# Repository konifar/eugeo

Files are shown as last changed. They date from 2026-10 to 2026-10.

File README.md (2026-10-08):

# eugeo

6 キー × 4 行 × 2 ブロック（48 キー）のスルーホール・オーソリニア 40% キーボード PCB です。
[Lumberjack](https://github.com/peej/lumberjack-keyboard)（Paul James 作、MIT License）をベースに、行を 1 段減らし、Kailh の MX 用ホットスワップソケットに対応させました。

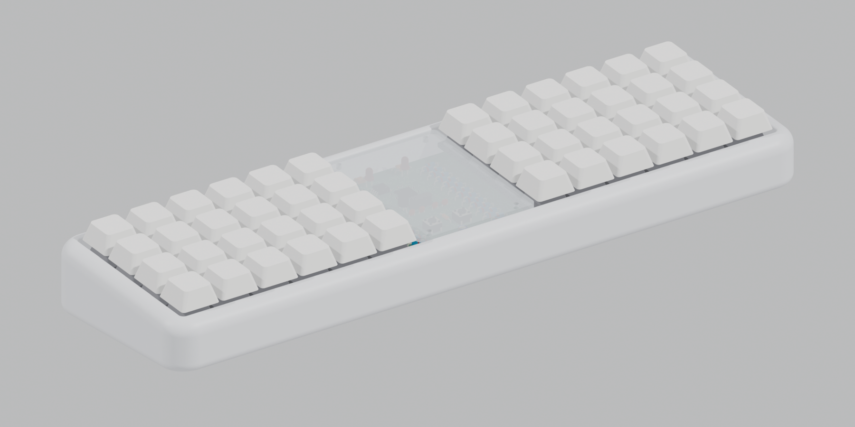
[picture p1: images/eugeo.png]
eugeo


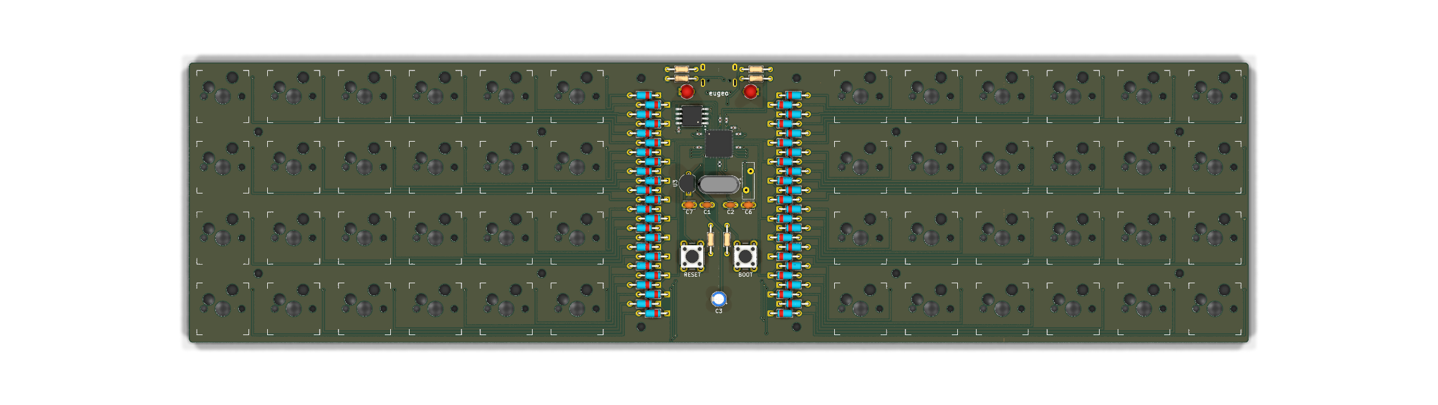
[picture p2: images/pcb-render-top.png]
PCB render


| 真上 | 背面 | 側面（6°） |
|---|---|---|
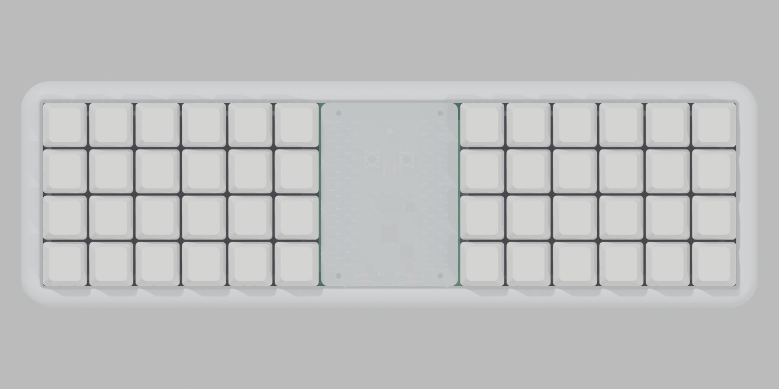
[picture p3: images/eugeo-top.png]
top
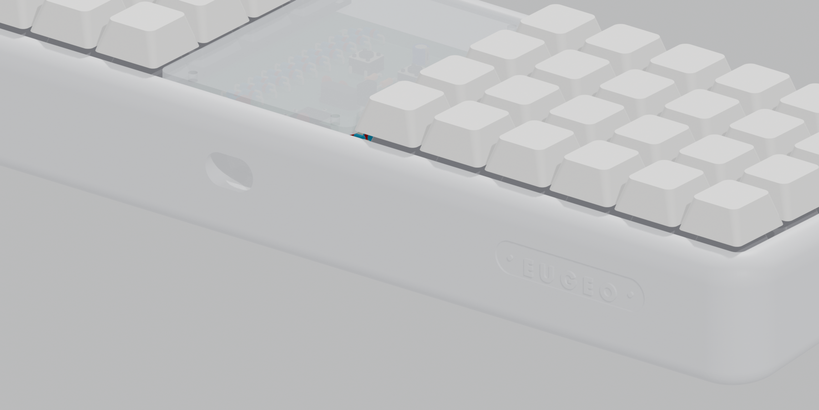
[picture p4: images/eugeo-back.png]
back
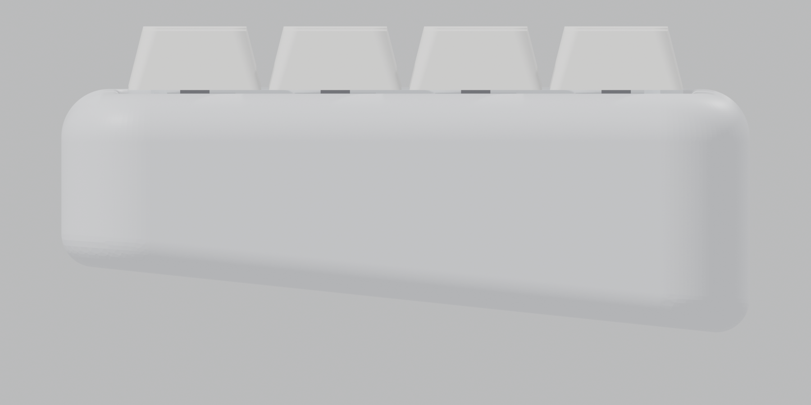
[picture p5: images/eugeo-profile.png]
profile
|  |  |  |

組み上がりの画像のスイッチとキーキャップは、大きさと位置の目安として置いた簡易形状です（`scripts/preview_models.py`）。

## Lumberjack からの変更点

| | Lumberjack Rev 1.8 | eugeo Rev 1.0 |
|---|---|---|
| 配列 | 5 × 12（60 キー） | 4 × 12（6 × 4 × 2、48 キー） |
| スイッチ | はんだ付け | Kailh MX ホットスワップソケット（裏面） |
| マトリクス | 6 行 × 10 列 | 8 行 × 6 列（後述） |
| USB-C | 左上・裏面 | 中央上・裏面（ソケットとの干渉回避） |
| 外形 | 60% トレイマウントケース互換 | 284.9 × 75.35 mm、M2 穴 8 箇所でサンドイッチ |
| ドーターボード用コネクタ (J3-J5) | あり | 削除 |
| 中央カバー | 2 mm アクリル、M2 10 mm スペーサー 4 本 | 同じ構成（ネジはカバーの四隅） |
| マイコン | ATmega328P-PU（DIP）+ V-USB（USB 1.1 Low Speed） | RP2040 + 2 MB QSPI フラッシュ（USB Full Speed、UF2 書き込み） |
| 電源 | USB 5 V 直結 | MCP1700 で 3.3 V（TO-92） |
| 書き込み | ISP ヘッダ（2x3） | BOOT ボタン + USB（UF2）。ISP ヘッダは不要になったので削除 |

マイコンまわりの表面実装部品（RP2040、フラッシュ、0402 のコンデンサなど）は JLCPCB に実装してもらい、それ以外はスルーホール部品のまま残しています。
上部の左右に 1 個ずつの LED、水晶（HC49）、セラミック・電解コンデンサ、LDO（TO-92）、アキシャル抵抗、タクトスイッチ、ダイオード列が中央に並ぶ、Lumberjack の「部品を見せる」見た目を踏襲しています。

## マトリクス

左右のブロックで行を分け、列を共有させた 8 行 × 6 列です。
左右の対称位置の列（左 C0 と右 C11 など）を基板下端の 1 本の配線で共有するので、ROW の配線が MCU をまたがずに済みます。
RP2040 の左辺のピンから左ブロックの行・列 3 本・LED1、右辺のピンから右ブロックの行・列 3 本・LED2 を出し、下辺は水晶と RUN、上辺は QSPI フラッシュと USB に使っています。

| 物理位置 | マトリクス |
|---|---|
| 左ブロック (row r, col c) | ROW r, COL c |
| 右ブロック (row r, col 6+j) | ROW r+4, COL 5-j |

| 設定 | 値 |
|---|---|
| MATRIX_ROW_PINS | GP3, GP4, GP5, GP6, GP26, GP25, GP24, GP23 |
| MATRIX_COL_PINS | GP9, GP10, GP11, GP20, GP19, GP18 |
| DIODE_DIRECTION | COL2ROW |
| LED1 (赤) / LED2 (緑) | GP1 / GP28（上部の左右） |
| BOOT ボタン | QSPI_SS（RP2040 標準の BOOTSEL。1k 経由で GND に落とす） |

## ファイル構成

| パス | 内容 |
|---|---|
| `eugeo.kicad_pro` / `.kicad_sch` / `.kicad_pcb` | KiCad 9 プロジェクト |
| `symbols/`, `footprints/eugeo.pretty/` | プロジェクト専用シンボル・フットプリント（ホットスワップソケット、USB-C、M2 穴） |
| `plates/` | スイッチプレート（左右共通、2 枚注文）、中央カバー、ボトムプレートの KiCad データと DXF |
| `case/` | Mojo60 風の丸いトレイケースと中央カバーの STEP / STL |
| `foam/` | プレートフォームとケースフォームの DXF と原寸 PDF |
| `lasercut/yushakobo/` | 遊舎工房レーザー加工サービス用の SVG（中央カバー / スイッチプレート / フォーム） |
| `jlcpcb/` | JLCPCB 実装用 BOM / CPL（表面実装部品とホットスワップソケット） |
| `jlcpcb/full/` | USB-C とスルーホール部品まで JLCPCB に実装してもらう場合の BOM / CPL |
| `gerbers/*.zip` | 製造用ガーバー（PCB、プレート、ボトム） |
| `firmware/qmk/keyboards/eugeo/` | QMK 用キーボード定義とキーマップ（default / via） |
| `firmware/*.uf2` | ビルド済みファームウェア |
| `scripts/` | 回路図・基板・裏面アート（`stump_art.py`）を生成するスクリプト一式 |

## 生成手順

回路図と基板は `scripts/design.py` を唯一の定義として生成しています。
部品配置やネットを変えるときは `design.py` を編集して再生成してください。

```bash
FREEROUTING_JAR=/path/to/freerouting-2.1.0.jar scripts/build_all.sh
```

1. `gen_schematic.py` で回路図を生成し、`check_netlist.py` で `design.py` とネットを照合
2. `build_pcb.py` で部品配置と、キー部分・ダイオード列・USB 端子・RP2040 まわりの配線を引く。RP2040 は電源ピンをパッドの内側の +3V3 リングでまとめ、QSPI・水晶・パスコン・各ピンの引き出しまでを手配線している
3. `route.sh` で残り（引き出した先から各部品まで）を Freerouting 2.1.0 で自動配線
4. `cleanup_dangling.py` で余った配線を削除し、`fill_zones.py` で表裏の GND ベタを流し、`stump_art.py` で裏面のアートを描く
5. DRC（回路図との整合チェック込み）

Freerouting の結果は実行ごとに変わり、まれに未配線が残ります。その場合は `build_all.sh` を再実行してください。
Freerouting 2.1.0 は Java 21 で動きます（2.2 以降は Java 25 が必要）。
初回起動時にできる設定ファイル（macOS では `$TMPDIR/freerouting/freerouting.json`）はテレメトリが有効なので、`allow_telemetry` を `false` にしておくことを勧めます。

製造データは次のコマンドで出力します。

```bash
scripts/export_fab.sh
```

## 製造（JLCPCB）

2026-10-06 に JLCPCB / JLC3DP の見積もりページへアップロードし、次のとおり受け付けられることを確認しました（カート投入・注文はしていません）。

| 部品 | ファイル | JLCPCB の認識 | 見積もり（参考） |
|---|---|---|---|
| PCB | `gerbers/eugeo.zip` | 2 層、284.9 × 75.35 mm | 5 枚 ¥2,269 + 送料 ¥1,536 |
| スイッチプレート | `gerbers/eugeo-plate.zip` | 2 層、113.45 × 75.35 mm。外形レイヤーにスイッチ穴 24 個と M2 穴 4 個 | 5 枚 ¥630 |
| ケース | `case/eugeo-case.step` | 302.9 × 93.4 × 29.9 mm、198.09 cm³（ふちを上げる前の版） | 9600 Resin 白 1 個 ¥2,978 + 送料 ¥1,139 |

PCB の注文設定は既定値（FR-4、1.6 mm、HASL）のままで問題ありません。色は好みで変えてください。
スイッチプレートは銅箔のない基板として注文します。JLCPCB の 2D プレビューでは穴が描かれませんが、Gerber Viewer の Layers 表示で外形に穴が入っていることを確認できます。左右共通なので 2 枚以上あれば足ります。
ボトムプレート（`gerbers/eugeo-bottom.zip`）はケースを使わない場合だけ必要です。

ケースは JLC3DP の 3D Printing で `case/eugeo-case.step`（または `.stl`）をアップロードし、素材に SLA レジン（9600 Resin など）を選びます。
最大造形サイズ（9600 Resin は 780 × 780 × 530 mm）には十分収まります。

### 表面実装部品とソケットの実装を JLCPCB に頼む

RP2040 まわりの表面実装部品（表面）とホットスワップソケット 48 個（裏面）を JLCPCB の PCBA で実装し、残りのスルーホール部品は自分ではんだ付けする想定です。
表裏両面の実装になるので Standard PCBA を選び、Assembly Side は **Both Sides** にして次のファイルをアップロードします。

| ファイル | 内容 |
|---|---|
| `jlcpcb/eugeo-bom.csv` | ソケット（LCSC C41430893）と表面実装部品（RP2040 C2040、W25Q16JVSSIQ C131025、USBLC6-2SC6 C7519、0402 のコンデンサ・抵抗。R7 / R8 / C12 / C13 / U4 は裏面） |
| `jlcpcb/eugeo-cpl.csv` | 実装座標（ガーバーと同じ原点）。ソケットは本体中心・裏面・回転 0、表面実装部品は KiCad の部品位置 |

2026-10-08 に実際にアップロードして確認した結果です（カート投入・注文はしていません）。

- ガーバー: 2 層、284.9 × 75.35 mm として受け付け。Standard PCBA では JLCPCB が上下に 5 mm の捨て基板（エッジレール）を付けるので、届いた基板はレールを折って外す（有料の Depanel オプションで外してもらうこともできる）
- BOM: 7 品目すべてが LCSC 部品に一致（RP2040 C2040、W25Q16JVSSIQ C131025、USBLC6-2SC6 C7519、0402 のコンデンサ・抵抗、ソケット C41430893）
- 部品配置プレビューで、RP2040・フラッシュ・USBLC6 の 1 番ピンとリードがフットプリントに合うことを確認。KiCad の角度のままではフラッシュ（SOIC-8、表）と USBLC6（SOT-23-6、裏）が 90° ずれていたので、`scripts/export_jlc_pcba.py` の `ROT_OFFSET` で補正済み。USBLC6 は 180° 間違えると GND と VBUS が入れ替わるので、部品を変えたときは必ずプレビューで確かめる
- ソケットの回転は 2026-10-06 に確認済み（突起が φ3.05 穴に、端子がパッドに重なる）
- 見積もり: 5 枚で ¥18,706（PCB ¥2,490、PCBA ¥16,215。うち初期費用 ¥8,117、ステンシル ¥2,607、部品 ¥3,406）、送料別

Kailh 純正ソケット（C5184526）にしたい場合は `scripts/export_jlc_pcba.py` の `LCSC` を書き換えてください。

### すべての部品の実装を JLCPCB に頼む

USB-C とスルーホール部品（ダイオード 48 本、抵抗、コンデンサ、水晶、レギュレータ、ヒューズ、タクトスイッチ、LED）まで JLCPCB に付けてもらう場合は、`jlcpcb/` の代わりに `jlcpcb/full/` をアップロードします（`python3 scripts/export_jlc_pcba.py --full` で生成）。はんだ付けは不要になり、届いたらスイッチを挿すだけです。

2026-10-08 にアップロードして確認した結果です（カート投入・注文はしていません）。

- BOM: 22 品目すべてが LCSC 部品に一致し、在庫あり
- スルーホール部品の座標は KiCad の原点（1 番ピン）ではなくパッドの中心にしている。USB-C は SMD なので部品位置のまま
- 部品配置プレビューで向きを確認。JLCPCB のモデルでは 3 mm LED のカソードと USB-C の差し込み口が逆向きだったので、`ROT_OFFSET` で 180° 補正済み
- 見積もり: 5 枚で ¥27,679（PCB ¥2,490、PCBA ¥25,188。うち初期費用 ¥8,117、ステンシル ¥2,607、部品 ¥6,949、フィーダー ¥1,954、手はんだ ¥569、手作業実装 ¥1,989、治具 ¥2,607）、送料別。表面実装部品とソケットだけの場合より ¥8,973 高い
- コンデンサ C6 / C7（C1620326）は単価が高く在庫も少なめ（確認時 34 個）、レギュレータ U3（C511277）も在庫 349 個。注文時に在庫切れなら同等品に差し替える

## 裏面のデザイン

基板の裏面は「凍てついた切り株」がテーマです（`scripts/stump_art.py`、`build_all.sh` の中で自動生成）。

- 裏返して左側（表から見て右ブロックの 1 段目と 2 段目の間）に、ケース背面の刻印と同じ Futura の「EUGEO」ロゴを大きく入れている。文字の高さ 7.5 mm、両側に細い線と丸を添える。文字の輪郭は `scripts/logo_outline.py` で `scripts/logo_eugeo.json` に書き出したもの

- 中央に年輪・樹皮・干割れのある切り株をシルクで描き、左右の端に向かって霜の結晶（シダ状の霜）が伸びる
- キーの並ぶ部分にはシルクの雪の結晶を散らす
- 大きめの雪の結晶 7 個はソルダーレジストの開口で、GND ベタの銅がそのまま（HASL なら銀色に）見える。配線・ビア・穴のない GND ベタの上にだけ置く
- シルクはパッド・穴・既存の文字の周りで自動的に切り取り、DRC の警告が出ないようにしている

レジストの色は青（Blue）を勧めます。白いシルクと銀色の結晶が氷のように見えます。

## ケース

Mojo60 を意識した、角と上下のふちを大きく丸めた一体型のトレイケースです。

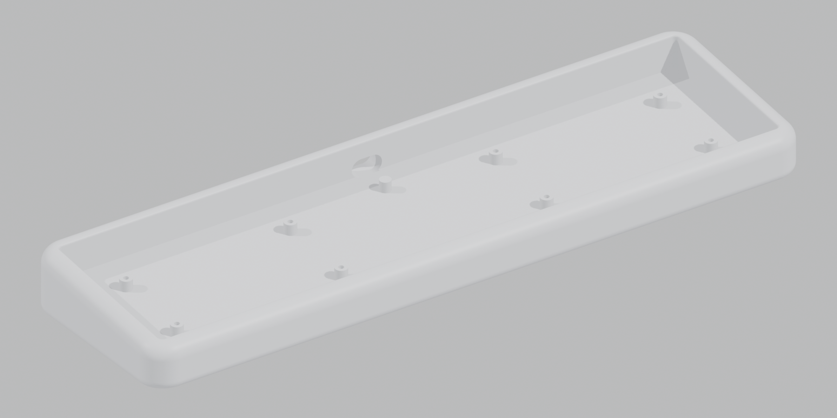
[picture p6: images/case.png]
Case


| 項目 | 値 |
|---|---|
| 外形 | 302.9 × 93.4 mm、高さ 手前 23.1 mm / 奥 32.9 mm |
| 傾斜 | 6° |
| 角の丸み | 平面 R12、上面のふち R6.5、底面のふち R4.5 |
| ふち | プレート上面から 6.5 mm 上（スイッチの上部が隠れ、キーキャップはその上に出る高さ） |
| 基板と壁のすき間 | 1.0 mm（キーキャップと壁の間は約 1.1 mm） |
| 底面 | 肉抜きして、幅 6 mm のふちで接地 |
| 刻印 | 奥の壁に「EUGEO」の銘板（後述） |

### 刻印

奥の壁の USB-C の横（背面から見て右）に、銘板風の刻印を入れています。
USB-C の切り欠きと同じ高さ 8.5 mm の長円を 0.6 mm 掘り下げ、Futura の「EUGEO」（文字高さ約 4.4 mm、字間広め）と両端の小さな鋲を元の壁面の高さで残しています。
USB-C の切り欠きと形・高さを揃えて、背面の 2 つの要素が並んで見えるようにしました。

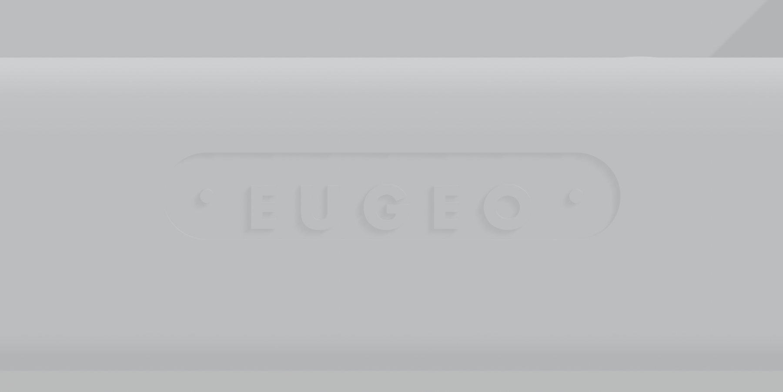
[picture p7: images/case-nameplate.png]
Nameplate


文字・フォント・位置・深さは `scripts/case.py` の `BADGE_*` 定数で変えられます。

寸法は `scripts/case.py` の先頭にある定数で変えられます。再生成の手順は次のとおりです。

```bash
uv venv --python 3.12 .venv && uv pip install --python .venv/bin/python build123d
.venv/bin/python scripts/case.py
kicad-cli pcb export step --subst-models -o /tmp/eugeo-pcb.step eugeo.kicad_pcb
.venv/bin/python scripts/check_case_fit.py /tmp/eugeo-pcb.step   # 基板・部品・プレートとの干渉チェック
```

### 組み立て

レジンには熱圧入インサートが使えないため、ネジはケースの底から通します。

1. 基板の上面から M2 3.5 mm のメス-メススペーサーを当て、ケースの底から M2×10 のなべネジで、ケースの支柱と基板を挟んで締める
2. スイッチをプレートにはめ、基板のソケットに差し込む
3. 必要ならプレートの上から M2×3 でスペーサーに留める（スイッチとソケットだけでも固定される）

奥の壁の USB-C 用の切り欠きは 14 × 8.5 mm です。プラグのモールド部分がこれより大きいケーブルは奥まで刺さりません。
底面のふちに小さいゴム足を貼ってください。

## 中央カバー

Lumberjack と同じく、中央の部品（ダイオード列・MCU・USB 周り）を透明な板で覆えます。

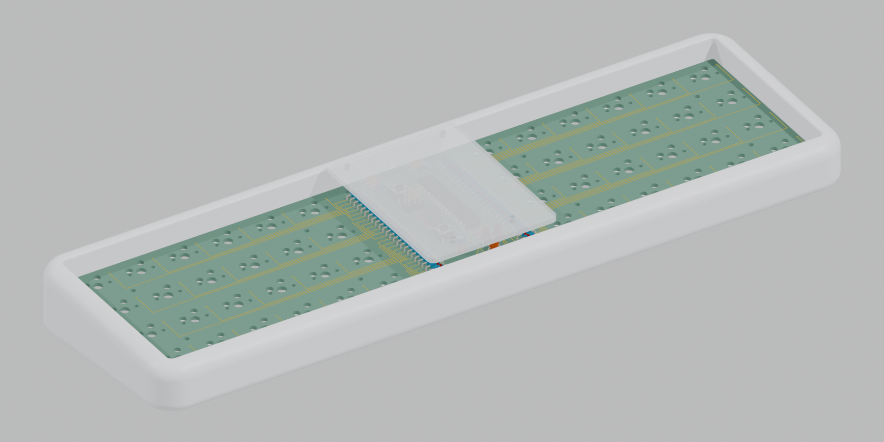
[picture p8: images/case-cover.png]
Centre cover


| 項目 | 値 |
|---|---|
| 大きさ | 56.2 × 75.35 mm、角 R3、厚さ 2 mm |
| 取り付け | カバーの四隅に合わせた基板の M2 穴 4 か所（H9〜H12）に M2 10 mm のメス-メススペーサーを立て、下から M2×4 で基板に、上から M2×4 でカバーを留める |
| 高さ | カバーの下面は基板上面から 10 mm。下でいちばん高い LED1（8.29 mm）との間に 1.71 mm のすき間 |
| ケースとの関係 | カバーの上面はケースのふちより約 0.5 mm 上。ケース・キーキャップとは重ならない |

| ファイル | 用途 |
|---|---|
| `plates/eugeo-cover.dxf` | アクリル板のレーザーカット用（推奨） |
| `case/eugeo-cover.step` / `.stl` | 3D プリントや CNC 用 |
| `gerbers/eugeo-cover.zip` | JLCPCB で FR4 板として作る場合（不透明になる） |

JLCPCB の基板サービスでは透明な板は作れないため、透明にしたい場合はアクリルのレーザーカットサービスに DXF を出してください。
JLC3DP の SLA で作る場合は、見積もり画面で透明系のレジンが選べるか確認してください。

## フォーム

打鍵音とたわみの調整用に、2 種類のフォームの型を用意しました。どちらも左右同じ形なので、1 つの型で 2 枚切り、片方は裏返して使います。

| ファイル | 位置 | 推奨素材 | 形 |
|---|---|---|---|
| `foam/eugeo-plate-foam` | プレートと PCB の間（3.5 mm） | 3 mm PORON | プレートと同じ外形、スイッチ下部を逃がす 14.5 mm 角穴、スペーサー用 φ4.4 穴 |
| `foam/eugeo-case-foam` | PCB とケース底の間（5 mm） | 3 mm PORON | キー部分のみ（中央の部品エリアは空ける）、ケースの支柱用 φ7 穴 |

`.dxf` はレーザーカット業者向け、`-1to1.pdf` は手で切るための原寸の型紙です。PDF は A4 横で、倍率 100% で印刷し、100 mm のスケールバーで寸法を確かめてから使ってください。
ケースフォームは 3 mm にすると、裏面のソケット（高さ約 1.85 mm）との間にほぼすき間がない厚さになります。
JLCPCB ではフォームのカットは扱っていないため、遊舎工房のレーザー加工（下記）に出すか手で切ってください。
スイッチプレート（`gerbers/eugeo-plate.zip`）は、ケースの内側に 1 mm のすき間で収まり、ケースのふちより 6.5 mm 低い位置に来ることを確認済みです。

## 遊舎工房のレーザー加工

[遊舎工房のレーザー加工サービス](https://yushakobo.jp/lasercut/)に、そのまま入稿できる SVG を `lasercut/yushakobo/` に用意しました。
遊舎工房配布の Inkscape テンプレートを土台にし、注文サイズの作業領域だけを残しています。

| ファイル | 注文するサービス / 素材 / 厚さ / サイズ | 中身 |
|---|---|---|
| `eugeo-cover_acrylic-clear-2mm_115x300.svg` | [レーザー加工サービス](https://shop.yushakobo.jp/products/lasercut)（アクリル）/ アクリル クリア / 2mm / 115x300 | 中央カバー 1 枚 |
| `eugeo-switch-plate_pom-1.5mm_245x245.svg` | [レーザー加工サービス（その2）](https://shop.yushakobo.jp/products/lasercut-2) / POM / 1.5mm / 245x245 | スイッチプレート 2 枚（左右共通） |
| `eugeo-foam_poron-3mm_500x100.svg` | レーザー加工サービス（その2）/ PORON / 3mm / 500x100 | プレートフォーム 2 枚 + ケースフォーム 2 枚 |

- 穴などの内側はカット①（赤）、外形はカット②（青）です。内側を先に切ってから部品を切り離す順番になります
- 線幅 0.001 mm、塗りなし、RGB、ファイル名は半角英数字です。シート端から 8 mm、部品同士は 5 mm 空けています（規定は 3 mm / 2 mm 以上）
- レーザーは線の上を切るため、穴は線より少し大きく、外形は少し小さく仕上がります。POM プレートのスイッチ穴（14.0 mm）が緩い場合は、注文時に相談してください
- スイッチプレートは JLCPCB の FR4（`gerbers/eugeo-plate.zip`）と POM のどちらで作っても同じ形です。POM のほうが打鍵感が柔らかくなります

テンプレートはリポジトリに含めていません。作り直すときは、遊舎工房の [Laser_Cut_template](https://drive.google.com/drive/folders/1BYeC-_gsrWUxI49BNqbQBk6OOC30LgTS) の Inkscape フォルダにある `Laser_acrylic_template.svg`、`Laser_POM_template.svg`、`Laser_Poron_template.svg` を 1 つのフォルダに置き（POM / Poron はファイル名を小文字の `pom` / `poron` にする）、次を実行します。

```bash
python3 scripts/export_yushakobo_svg.py <テンプレートのフォルダ>
python3 scripts/check_lasercut_svg.py
```

## 組み立て（基板）

- ホットスワップソケットと USB-C は裏面、それ以外の部品は表面に付けます
- ダイオードは帯（カソード）を MCU 側に向けます。左列はシルクの右側、右列は左側がカソードです
- プレートと PCB の間は 3.5 mm（1.5 mm 厚プレートでスイッチ底面が PCB に接する高さ）です
- ケースを使わずボトムプレートで挟む場合は、裏面の USB-C とソケットを避けるため PCB とボトムの間を 8 mm 程度空けます

## ファームウェア

`firmware/qmk/keyboards/eugeo` を qmk_firmware の `keyboards/` にコピーしてビルドします。
2026-10-07 時点の qmk_firmware でビルドできることを確認済みです。ビルド済みの `firmware/eugeo_default.uf2` / `firmware/eugeo_via.uf2` も置いてあります。

```bash
qmk compile -kb eugeo -km via
```

RP2040 は ROM にブートローダーを持っているので、ブートローダーの書き込みは要りません。

1. BOOT を押したまま RESET を押して離す（何も書き込まれていない新品の RP2040 は USB をつなぐだけでよい）
2. `RPI-RP2` という USB ドライブとして認識される
3. `eugeo_via.uf2` をそのドライブにコピーすると、書き込み後に自動で再起動する

`qmk flash -kb eugeo -km via` でも同じことができます。キーマップに `QK_BOOT` を割り当てておけば、BOOT ボタンを使わずに書き込みモードに入れます。

### Remap / VIA

`via` キーマップは VIA 対応（`VIA_ENABLE = yes`）で、[Remap](https://remap-keys.app) と VIA のどちらからでもキー配置を変えられます。

1. Chrome か Edge で Remap を開き、「Configure」から eugeo を接続する
2. Remap のカタログに未登録のうちは定義ファイルを求められるので、`firmware/via/eugeo.json` を読み込む

`firmware/via/eugeo.json` は VIA v3 形式の定義ファイルで、物理配列どおり左右ブロックの間を 3U 空けています。VIA の Design タブでもそのまま読み込めます。
Remap のカタログに登録すると、Remap の画面からファームウェアの書き込み（UF2 のダウンロードとコピーの案内）もできるようになります。

Remap のカタログに登録すれば、定義ファイルを読み込まなくても自動で認識されます。登録は Remap に GitHub アカウントでログインして申請し、ファームウェアのソースの場所（GitHub のリポジトリなど）を示します。
VID / PID（`0x6B6E` / `0x4547`）は自分で決めた値です。登録前に、他のキーボードと重複していないか Remap 上で確認してください。

## 動作の検証

実機は作っていないため、基板データからの検証で、はんだ付けすれば動くことを確認しています。

- KiCad の DRC: 違反 0、未接続 0、回路図との整合 OK。ERC も 0 件
- `scripts/verify_design.py`（59 項目すべて合格）
  - RP2040 のシンボルのピン名がデータシート（QFN-56）と一致すること
  - 電源: IOVDD 6 本・ADC_AVDD・VREG_VIN・USB_VDD が +3V3、VREG_VOUT が DVDD 2 本に、パスコンの数と RP2040 からの距離、MCP1700 のピン配置
  - 12 MHz 水晶と 1k 直列抵抗、22 pF、RUN のプルアップと RESET、BOOT（QSPI_SS を 1k で GND へ）
  - QSPI フラッシュの 8 ピンが RP2040 の QSPI 信号と一致すること
  - USB: D+ / D- が 27Ω 経由で USB_DP / USB_DM に、USBLC6、CC の 5.1k、VBUS のポリスイッチ
  - LED とコンデンサの極性、ダイオードの向き（COL2ROW）、QMK の LED ピン設定
  - 48 キーすべてについて、基板上の行・列の GPIO が QMK の `keyboard.json` と一致すること
- RP2040 まわりは、電源ピンをパッドの内側の +3V3 リングでまとめ、+1V1 は裏面経由で 3 ピンをつなぎ、QSPI・水晶・パスコン・行と列の引き出しまでを手配線しています。0.4 mm ピッチの間をすり抜ける配線はありません
- 中央カバー: カバー下面と部品の最小すき間 1.71 mm（LED1）、カバーとケース・部品の干渉 0（`scripts/check_case_fit.py`）
- ソケットのフットプリント: パッド位置・サイズが [keyswitch-kicad-library](https://github.com/perigoso/keyswitch-kicad-library) の SW_Hotswap_Kailh_MX_1.00u と一致。ソケットの突起が入る穴は同ライブラリに合わせて φ3.05 mm

```bash
KP=/Applications/KiCad/KiCad.app/Contents/Frameworks/Python.framework/Versions/Current/bin/python3
$KP scripts/verify_design.py
```

### 発注前チェック

発注の前に `scripts/preorder_check.py` を実行してください（2026-10-07 時点で 23 項目すべて合格）。DRC で見えない次の点を確かめます。

- 前の版との差分が、意図した部品の追加・削除だけであること（ほかのパッドの位置と接続が変わっていない）
- 全部品が `design.py` どおりの位置・向き・面にあり、外形も設計どおりであること
- スペーサー・ネジ頭・ケースの支柱が当たる範囲に、むき出しの銅箔がないこと。ビアがすべてレジストで覆われていること（マスクのガーバーでも確認）
- 実際の基板の最小値（線幅 0.15、ビア φ0.3 / 0.6、穴、スロット、シルク文字 1.0 mm）が JLCPCB の製造基準を満たすこと
- `gerbers/eugeo.zip` が今の基板から出したものと一致し、ドリルデータに M2 穴 12 個が設計位置どおりにあること
- JLCPCB の実装座標（ソケットと表面実装部品）と LCSC 番号、スイッチプレート・中央カバー・ボトムプレートの穴が基板の穴と一致すること
- 遊舎工房向け SVG が入稿ルールを満たすこと、59 項目の機能チェックが通ること

```bash
$KP scripts/preorder_check.py --base <前回発注した版の git リビジョン>
```

## 未検証の点

- 試作していません。上記の検証、ケースとの干渉チェックは通っています
- JLCPCB の部品の回転角はプレビューで確認しただけです。部品を変えたら注文時の配置プレビューで 1 番ピンの向きを確かめてください（上の「表面実装部品とソケットの実装を JLCPCB に頼む」）
- USB-C コネクタ（TYPE-C-31-M-12）は 0.5 mm ピッチの SMD で、手はんだでは一番難しい部品です（Lumberjack と同じ部品）
- ケースの USB-C 部はコネクタの 3D モデルがないため、寸法計算だけで確認しています
- ホットスワップソケットのフットプリントは keyswitch-kicad-library と同寸で、JLCPCB の部品配置とも一致しましたが、実物のソケットでの勘合は未確認です

## License

ハードウェア（回路図・基板・プレート・ケース・フォーム）とスクリプトは MIT License です。Lumberjack の著作権表示を `LICENSE` に残しています。
`firmware/qmk/` 以下のファームウェアは QMK に合わせて GPL-2.0-or-later です。

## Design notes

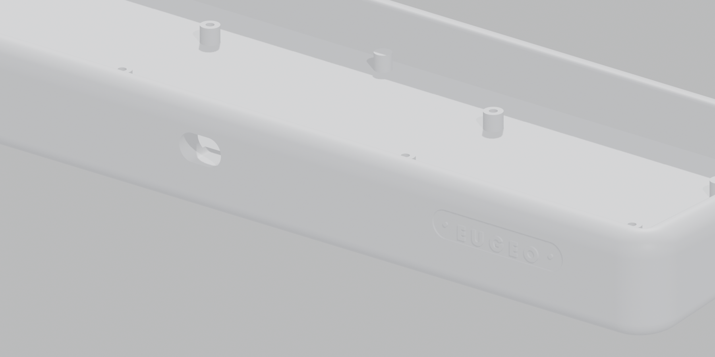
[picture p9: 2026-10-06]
images/case-back.png

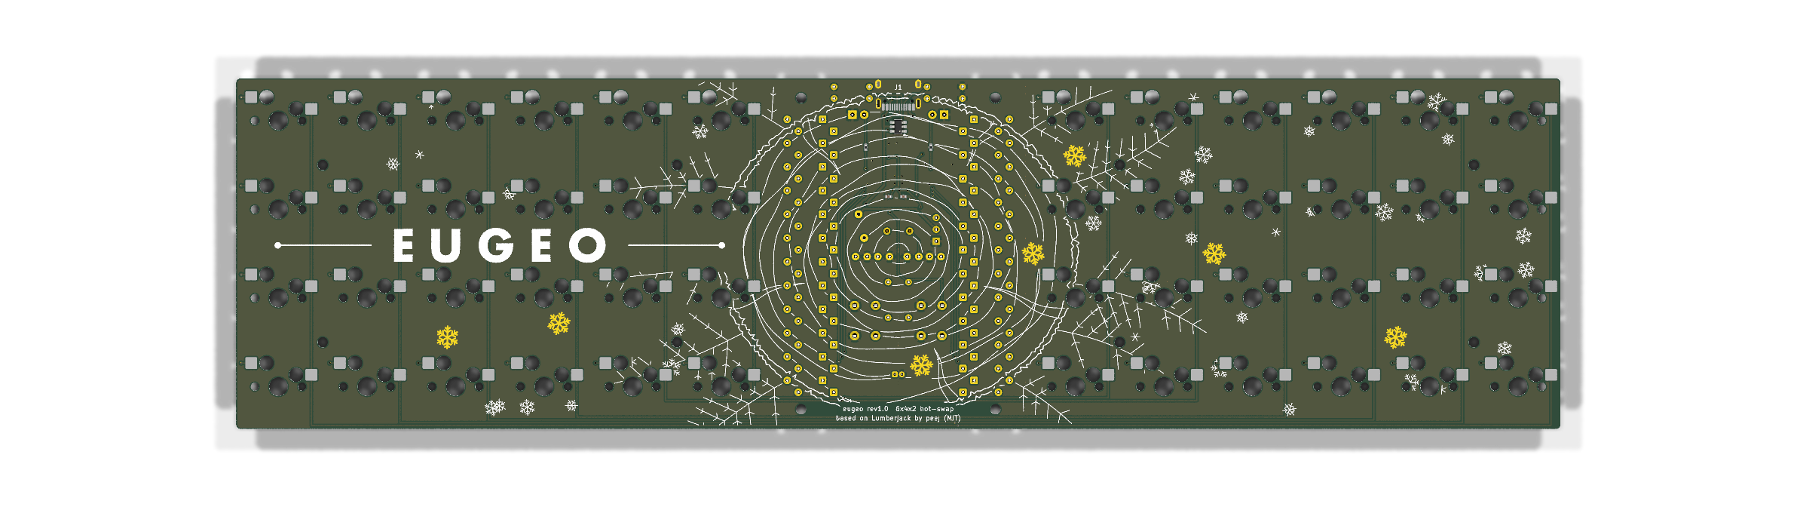
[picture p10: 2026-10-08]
images/pcb-render-bottom.png

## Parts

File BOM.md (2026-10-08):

# Bill of Materials (BOM)

| Ref | Qty | Value / Part# | Description | Vendor |
|---|---|---|---|---|
| U1, U2, U4, C10-C15, C17, C18, C20, C22, R7, R8, R11 | — | 下表 | 表面実装部品（JLCPCB が実装） | `jlcpcb/eugeo-bom.csv` |
| C1, C2 | 2 | 22pF p2.5mm | セラミックコンデンサ（水晶の負荷容量） | |
| C3 | 1 | 10uF p1.5mm (φ4mm) | 電解コンデンサ（+5V） | |
| C6, C7 | 2 | 1uF p2.5mm | 積層セラミックコンデンサ（MCP1700 の入力 / 出力） | |
| D1-D48 | 48 | 1N4148 | ダイオード | [秋月電子](https://akizukidenshi.com/catalog/g/g100941/) |
| F1 | 1 | 100mA | ポリスイッチ | [秋月電子](https://akizukidenshi.com/catalog/g/g112911/) |
| J1 | 1 | TYPE-C-31-M-12 | USB Type-C コネクタ（裏面実装） | [Amazon](https://www.amazon.co.jp/dp/B09PKH9XZY) |
| LED1, LED2 | 2 | 3mm | LED（LED1=Caps Lock, LED2=レイヤー） | [秋月電子 黄緑](https://akizukidenshi.com/catalog/g/g111637/) / [赤](https://akizukidenshi.com/catalog/g/g111577/) |
| MX1-MX48 | 48 | Kailh CPG151101S11 | MX 用ホットスワップソケット（裏面）。JLCPCB 実装なら LCSC C41430893（互換品） | |
| (switch) | 48 | MX 互換 | キースイッチ（3pin / 5pin どちらも可） | |
| R2, R3 | 2 | 27Ω | 抵抗（USB D+ / D- 直列） | |
| R5, R6 | 2 | 5.1kΩ | 抵抗（USB-C CC） | [秋月電子](https://akizukidenshi.com/catalog/g/g108547/) |
| R10 | 1 | 1kΩ | 抵抗（BOOT） | |
| R9 | 1 | 10kΩ | 抵抗（RUN プルアップ） | [秋月電子](https://akizukidenshi.com/catalog/g/g108550/) |
| SW1, SW2 | 2 | 6x6mm | タクトスイッチ（RESET / BOOT） | [Mouser](https://www.mouser.jp/ProductDetail/611-645SL70SMTR92LFS) |
| U3 | 1 | MCP1700-3302E/TO | 3.3 V LDO（TO-92） | |
| Y1 | 1 | HC49-4H 12MHz | 水晶振動子 | |
| plate | 2 | `gerbers/eugeo-plate.zip` または `lasercut/yushakobo/eugeo-switch-plate_*.svg` | スイッチプレート（左右共通、FR4 1.5mm または POM 1.5mm） | JLCPCB / [遊舎工房](https://shop.yushakobo.jp/products/lasercut-2) |
| case | 1 | `case/eugeo-case.step` | ケース（JLC3DP SLA レジン） | |
| standoff | 8 | M2 3.5mm メス-メス | PCB - プレート間（1.5mm 厚プレートの場合） | |
| screw | 8 | M2×10 なべ | ケース底 → PCB → スペーサー | |
| screw | 8 | M2×3 | プレート → スペーサー（任意） | |
| feet | 4〜6 | ゴム足 | ケース底のふちに貼る | |
| cover | 1 | `lasercut/yushakobo/eugeo-cover_*.svg` | 中央カバー（アクリル クリア 2mm、遊舎工房レーザー加工） | [遊舎工房](https://shop.yushakobo.jp/products/lasercut) |
| standoff | 4 | M2 10mm メス-メス | PCB - 中央カバー間 | |
| screw | 8 | M2×4 | 中央カバーのスペーサー固定（PCB 下 4 本 + カバー上 4 本） | |
| plate foam | 2 | 3mm PORON | `foam/eugeo-plate-foam`（任意） | [遊舎工房](https://shop.yushakobo.jp/products/lasercut-2) |
| case foam | 2 | 3mm PORON | `foam/eugeo-case-foam`（任意） | [遊舎工房](https://shop.yushakobo.jp/products/lasercut-2) |

ケースを使わない場合は、ケースの代わりにボトムプレート（`gerbers/eugeo-bottom.zip`）、PCB とボトムの間に M2 8mm スペーサー 8 本、M2×4 ネジ 16 本を使います。

ホットスワップ基板なので、スイッチはプレートで固定する前提です。

## 表面実装部品（JLCPCB）

RP2040 まわりの表面実装部品は JLCPCB の PCBA で実装します（`jlcpcb/eugeo-bom.csv` / `eugeo-cpl.csv`）。C12 / C13 / R7 / R8 / U4 は裏面です。

| Ref | Qty | Value / Part# | LCSC | Description |
|---|---|---|---|---|
| U1 | 1 | RP2040 | C2040 | マイコン（QFN-56） |
| U2 | 1 | W25Q16JVSSIQ | C131025 | QSPI フラッシュ 2 MB（SOIC-8 208mil） |
| U4 | 1 | USBLC6-2SC6 | C7519 | USB ESD 保護（裏面） |
| C10-C15, C20, C22 | 8 | 100nF 0402 | C1525 | パスコン |
| C17, C18 | 2 | 1uF 0402 | C52923 | VREG_VIN / VREG_VOUT |
| R7, R8, R11 | 3 | 1kΩ 0402 | C11702 | LED の電流制限（裏面）、水晶の直列抵抗 |

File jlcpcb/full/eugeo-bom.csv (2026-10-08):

Comment | Designator | Footprint | LCSC Part #
CPG151101S11 hot-swap socket | MX1,MX2,MX3,MX4,MX5,MX6,MX7,MX8,MX9,MX10,MX11,MX12,MX13,MX14,MX15,MX16,MX17,MX18,MX19,MX20,MX21,MX22,MX23,MX24,MX25,MX26,MX27,MX28,MX29,MX30,MX31,MX32,MX33,MX34,MX35,MX36,MX37,MX38,MX39,MX40,MX41,MX42,MX43,MX44,MX45,MX46,MX47,MX48 | Kailh_MX_Hotswap_Socket | C41430893
22p | C1,C2 | C_Disc_D3.0mm_W1.6mm_P2.50mm | C2170230
100n | C10,C11,C12,C13,C14,C15,C20,C22 | C_0402_1005Metric | C1525
1u | C17,C18 | C_0402_1005Metric | C52923
10u | C3 | CP_Radial_D4.0mm_P1.50mm | C43846
1u | C6,C7 | C_Disc_D3.0mm_W2.0mm_P2.50mm | C1620326
1N4148 | D1,D2,D3,D4,D5,D6,D7,D8,D9,D10,D11,D12,D13,D14,D15,D16,D17,D18,D19,D20,D21,D22,D23,D24,D25,D26,D27,D28,D29,D30,D31,D32,D33,D34,D35,D36,D37,D38,D39,D40,D41,D42,D43,D44,D45,D46,D47,D48 | D_DO-35_SOD27_P7.62mm_Horizontal | C84410
100mA | F1 | Fuse_Bourns_MF-RHT100 | C89660
USB-C | J1 | TYPE-C-31-M-12 | C165948
RED | LED1 | LED_D3.0mm | C99772
GREEN | LED2 | LED_D3.0mm | C85161
1k | R10 | R_Axial_DIN0204_L3.6mm_D1.6mm_P7.62mm_Horizontal | C2903331
27R | R2,R3 | R_Axial_DIN0204_L3.6mm_D1.6mm_P7.62mm_Horizontal | C119144
5.1k | R5,R6 | R_Axial_DIN0204_L3.6mm_D1.6mm_P7.62mm_Horizontal | C119195
1k | R7,R8,R11 | R_0402_1005Metric | C11702
10k | R9 | R_Axial_DIN0204_L3.6mm_D1.6mm_P7.62mm_Horizontal | C119202
RESET/BOOT | SW1,SW2 | SW_PUSH_6mm | C83205
RP2040 | U1 | QFN-56-1EP_7x7mm_P0.4mm_EP3.2x3.2mm | C2040
W25Q16JVSSIQ | U2 | SOIC-8_5.3x5.3mm_P1.27mm | C131025
MCP1700-3302E | U3 | TO-92_Inline_Wide | C511277
USBLC6-2SC6 | U4 | SOT-23-6 | C7519
12MHz | Y1 | Crystal_HC49-4H_Vertical | C16369

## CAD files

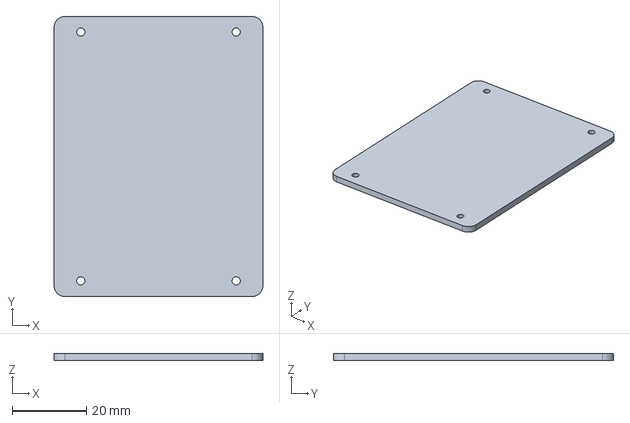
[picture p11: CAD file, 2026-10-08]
case/eugeo-cover.step
56.2 x 75.3 x 2.00 mm

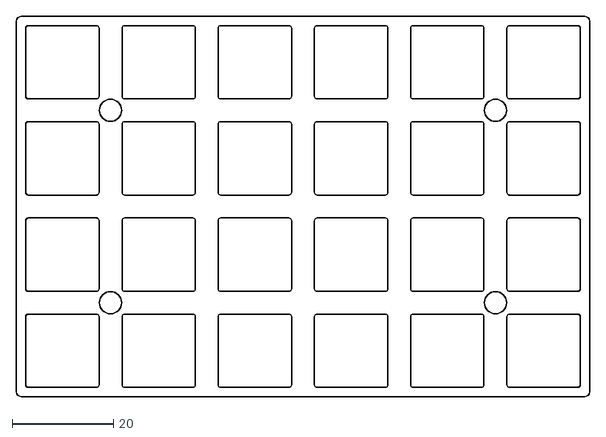
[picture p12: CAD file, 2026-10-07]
foam/eugeo-plate-foam.dxf
113.5 x 75.3

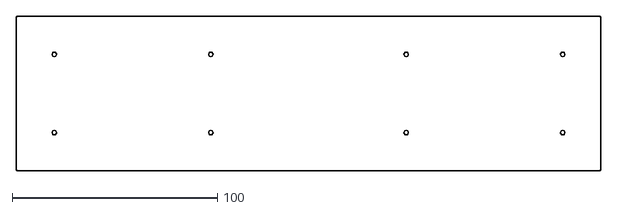
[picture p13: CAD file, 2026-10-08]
plates/eugeo-bottom.dxf
284.9 x 75.3

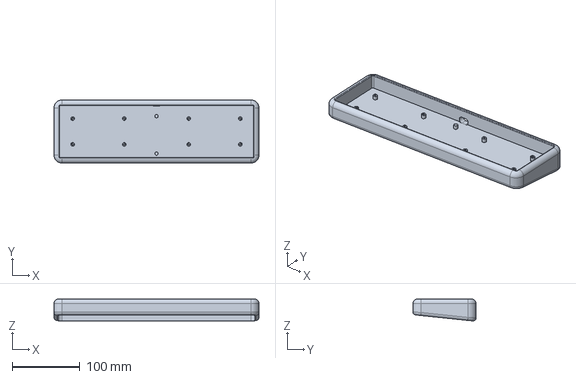
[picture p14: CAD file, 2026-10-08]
case/eugeo-case.step
302.9 x 93.3 x 32.4 mm

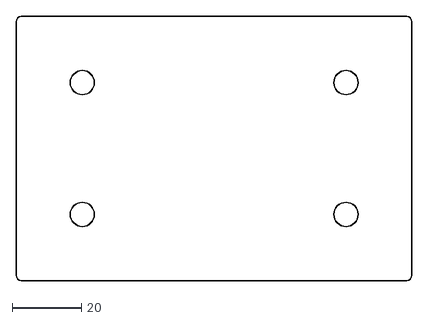
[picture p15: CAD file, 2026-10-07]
foam/eugeo-case-foam.dxf
114.3 x 76.3

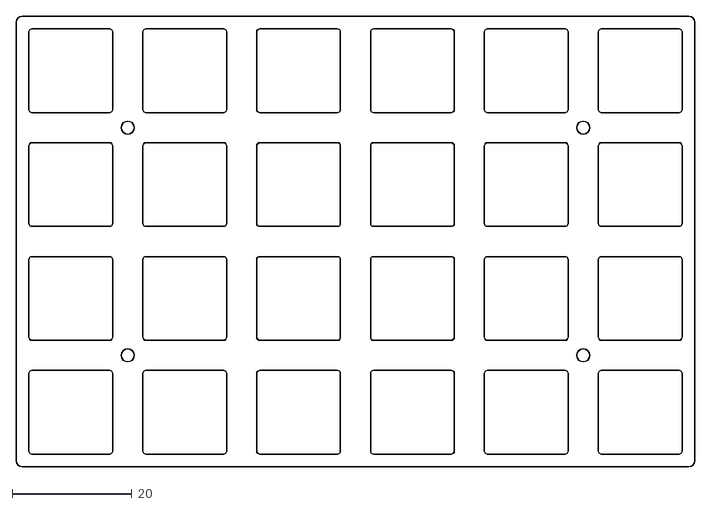
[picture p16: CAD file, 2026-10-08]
plates/eugeo-plate.dxf
113.4 x 75.3

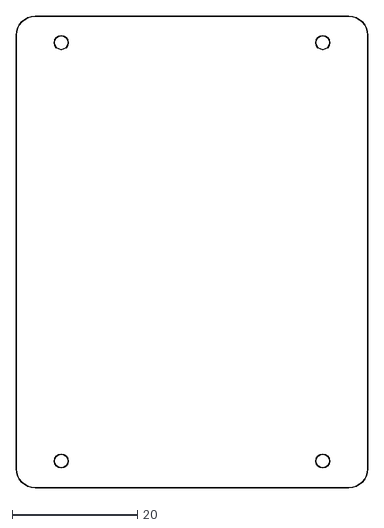
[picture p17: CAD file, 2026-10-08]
plates/eugeo-cover.dxf
56.2 x 75.3

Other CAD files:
case/eugeo-case.stl
case/eugeo-cover.stl

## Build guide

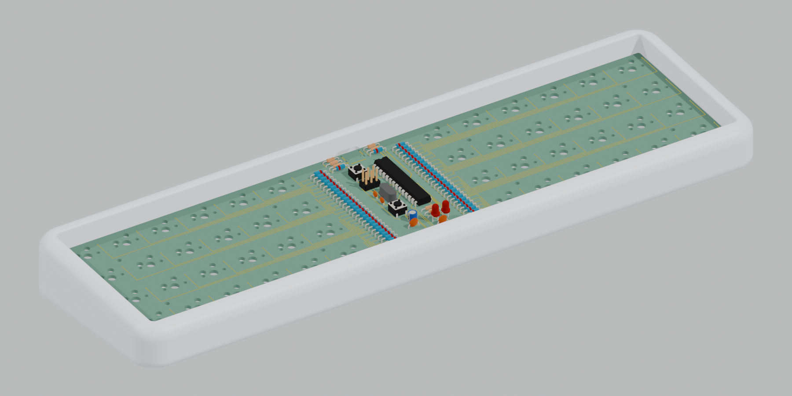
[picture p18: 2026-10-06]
images/case-assembly.png

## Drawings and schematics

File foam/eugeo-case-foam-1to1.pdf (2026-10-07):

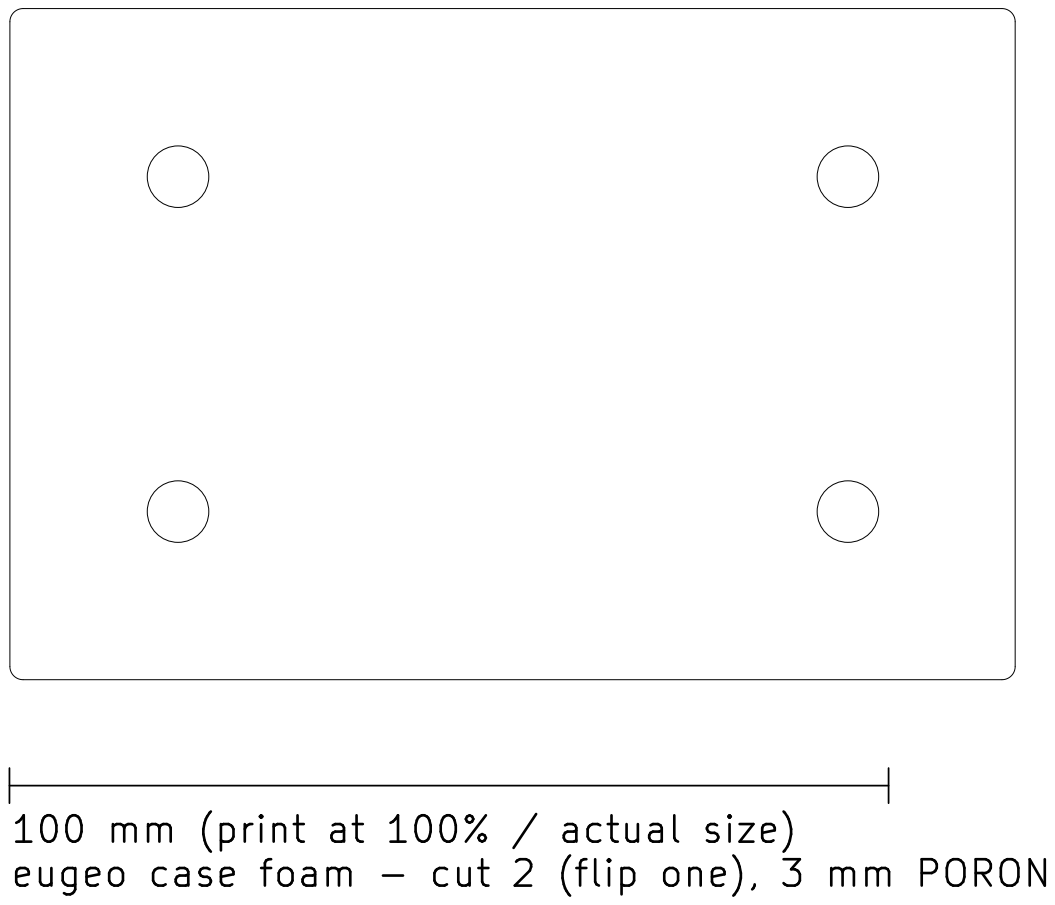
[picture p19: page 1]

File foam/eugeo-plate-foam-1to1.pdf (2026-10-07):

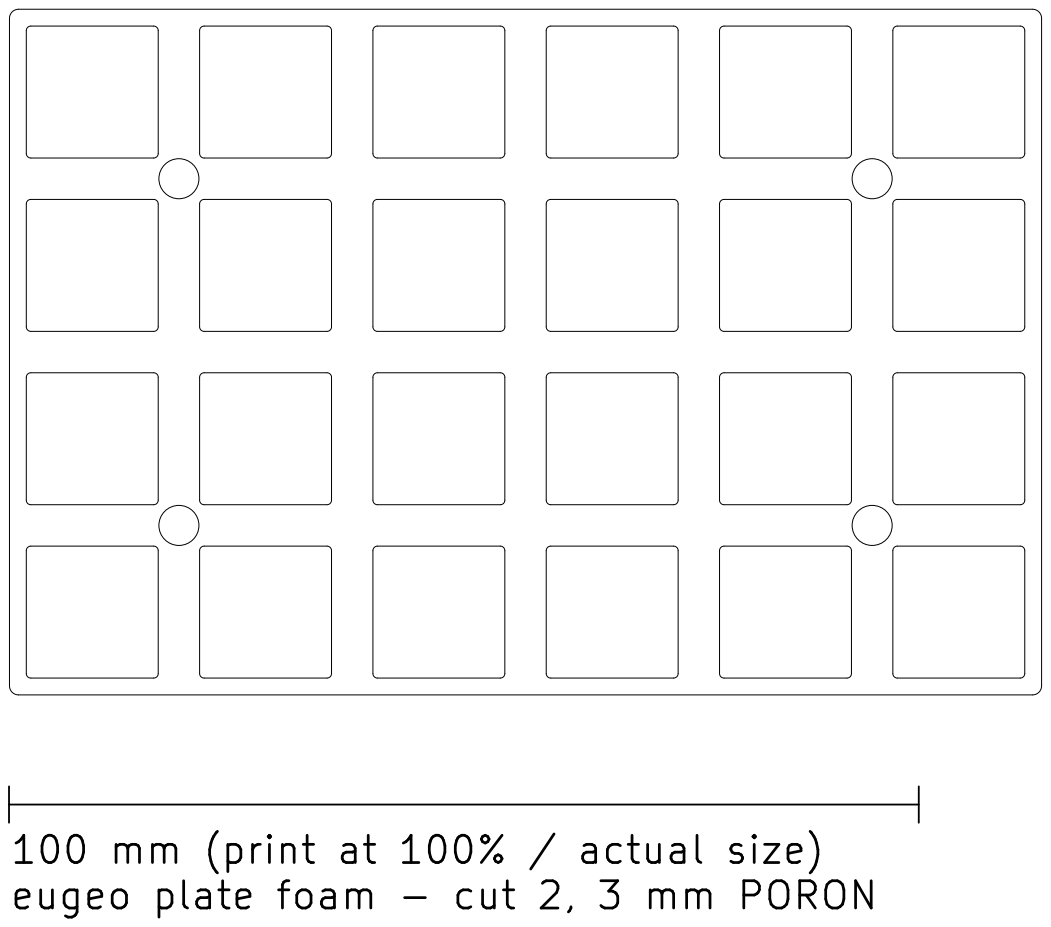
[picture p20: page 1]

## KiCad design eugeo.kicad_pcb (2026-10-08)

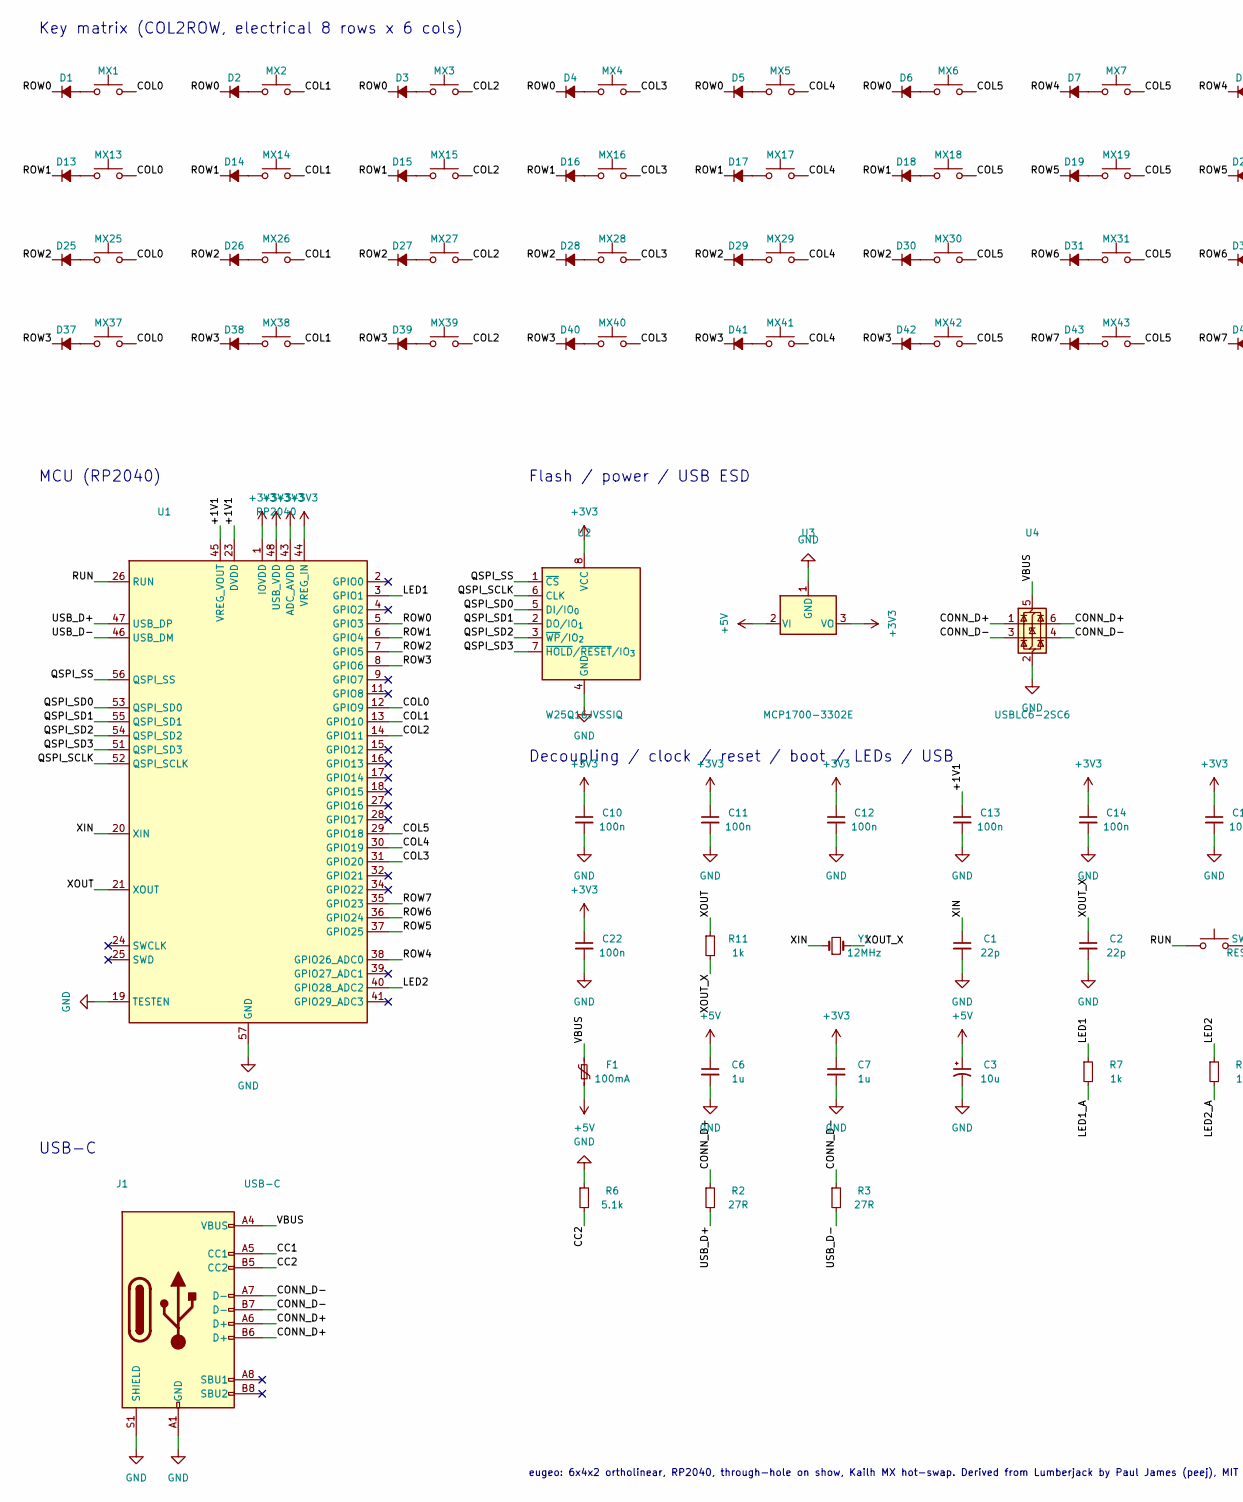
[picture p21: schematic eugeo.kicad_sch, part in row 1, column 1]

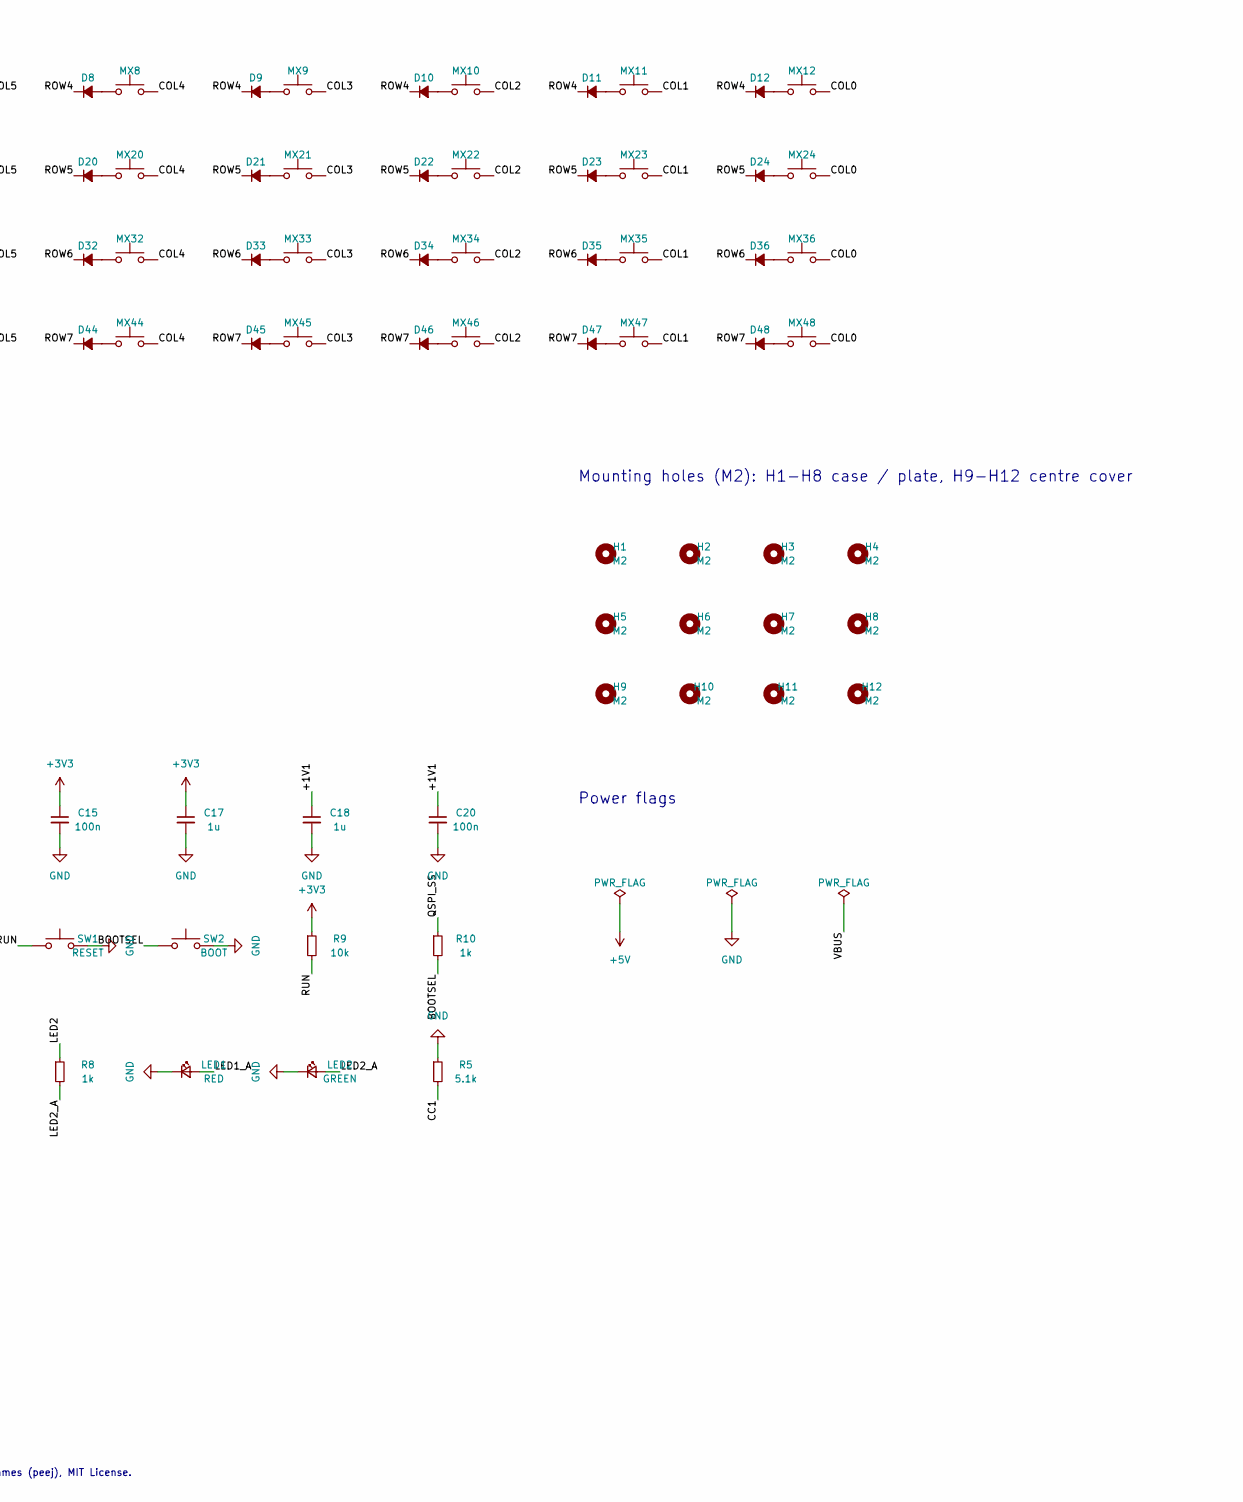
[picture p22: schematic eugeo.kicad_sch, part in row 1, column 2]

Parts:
C1, C2: 22p; C_Disc_D3.0mm_W1.6mm_P2.50mm
C3: 10u; CP_Radial_D4.0mm_P1.50mm
C6, C7: 1u; C_Disc_D3.0mm_W2.0mm_P2.50mm
C10, C11, C12, C13, C14, C15, C20, C22: 100n; C_0402_1005Metric
C17, C18: 1u; C_0402_1005Metric
D1, D2, D3, D4, D5, D6, D7, D8, D9, D10, D11, D12, D13, D14, D15, D16, D17, D18, D19, D20, D21, D22, D23, D24, D25, D26, D27, D28, D29, D30, D31, D32, D33, D34, D35, D36, D37, D38, D39, D40, D41, D42, D43, D44, D45, D46, D47, D48: 1N4148; D_DO-35_SOD27_P7.62mm_Horizontal
F1: 100mA; Fuse_Bourns_MF-RHT100
H1, H2, H3, H4, H5, H6, H7, H8, H9, H10, H11, H12: M2; MountingHole_M2_NPTH
J1: USB-C; TYPE-C-31-M-12
LED1: RED; LED_D3.0mm
LED2: GREEN; LED_D3.0mm
MX1, MX2, MX3, MX4, MX5, MX6, MX7, MX8, MX9, MX10, MX11, MX12, MX13, MX14, MX15, MX16, MX17, MX18, MX19, MX20, MX21, MX22, MX23, MX24, MX25, MX26, MX27, MX28, MX29, MX30, MX31, MX32, MX33, MX34, MX35, MX36, MX37, MX38, MX39, MX40, MX41, MX42, MX43, MX44, MX45, MX46, MX47, MX48: MX; MX_Hotswap_Kailh
R2, R3: 27R; R_Axial_DIN0204_L3.6mm_D1.6mm_P7.62mm_Horizontal
R5, R6: 5.1k; R_Axial_DIN0204_L3.6mm_D1.6mm_P7.62mm_Horizontal
R7, R8, R11: 1k; R_0402_1005Metric
R9: 10k; R_Axial_DIN0204_L3.6mm_D1.6mm_P7.62mm_Horizontal
R10: 1k; R_Axial_DIN0204_L3.6mm_D1.6mm_P7.62mm_Horizontal
SW1: RESET; SW_PUSH_6mm
SW2: BOOT; SW_PUSH_6mm
U1: RP2040; QFN-56-1EP_7x7mm_P0.4mm_EP3.2x3.2mm
U2: W25Q16JVSSIQ; SOIC-8_5.3x5.3mm_P1.27mm
U3: MCP1700-3302E; TO-92_Inline_Wide
U4: USBLC6-2SC6; SOT-23-6
Y1: 12MHz; Crystal_HC49-4H_Vertical

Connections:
+3V3: C7.1, C10.1, C11.1, C12.1, C14.1, C15.1, C17.1, C22.1, R9.1, U1.1 (IOVDD), U1.10 (IOVDD), U1.22 (IOVDD), U1.33 (IOVDD), U1.42 (IOVDD), U1.43 (ADC_AVDD), U1.44 (VREG_IN), U1.48 (USB_VDD), U1.49 (IOVDD), U2.8 (VCC), U3.3 (VO)
+5V: C3.1, C6.1, F1.2, U3.2 (VI)
/+1V1: C13.1, C18.1, C20.1, U1.23 (DVDD), U1.45 (VREG_VOUT), U1.50 (DVDD)
/BOOTSEL: R10.2, SW2.1
/CC1: J1.A5 (CC1), R5.2
/CC2: J1.B5 (CC2), R6.2
/COL0: MX1.2, MX12.2, MX13.2, MX24.2, MX25.2, MX36.2, MX37.2, MX48.2, U1.12 (GPIO9)
/COL1: MX2.2, MX11.2, MX14.2, MX23.2, MX26.2, MX35.2, MX38.2, MX47.2, U1.13 (GPIO10)
/COL2: MX3.2, MX10.2, MX15.2, MX22.2, MX27.2, MX34.2, MX39.2, MX46.2, U1.14 (GPIO11)
/COL3: MX4.2, MX9.2, MX16.2, MX21.2, MX28.2, MX33.2, MX40.2, MX45.2, U1.31 (GPIO20)
/COL4: MX5.2, MX8.2, MX17.2, MX20.2, MX29.2, MX32.2, MX41.2, MX44.2, U1.30 (GPIO19)
/COL5: MX6.2, MX7.2, MX18.2, MX19.2, MX30.2, MX31.2, MX42.2, MX43.2, U1.29 (GPIO18)
/CONN_D+: J1.A6 (D+), J1.B6 (D+), R2.1, U4.1 (I/O1), U4.6 (I/O1)
/CONN_D-: J1.A7 (D-), J1.B7 (D-), R3.1, U4.3 (I/O2), U4.4 (I/O2)
/LED1: R7.1, U1.3 (GPIO1)
/LED1_A: LED1.2 (A), R7.2
/LED2: R8.1, U1.40 (GPIO28_ADC2)
/LED2_A: LED2.2 (A), R8.2
/QSPI_SCLK: U1.52 (QSPI_SCLK), U2.6 (CLK)
/QSPI_SD0: U1.53 (QSPI_SD0), U2.5 (DI/IO_{0})
/QSPI_SD1: U1.55 (QSPI_SD1), U2.2 (DO/IO_{1})
/QSPI_SD2: U1.54 (QSPI_SD2), U2.3 (~WP/IO_{2})
/QSPI_SD3: U1.51 (QSPI_SD3), U2.7 (~HOLD/~RESET/IO_{3})
/QSPI_SS: R10.1, U1.56 (QSPI_SS), U2.1 (~CS)
/ROW0: D1.1 (K), D2.1 (K), D3.1 (K), D4.1 (K), D5.1 (K), D6.1 (K), U1.5 (GPIO3)
/ROW1: D13.1 (K), D14.1 (K), D15.1 (K), D16.1 (K), D17.1 (K), D18.1 (K), U1.6 (GPIO4)
/ROW2: D25.1 (K), D26.1 (K), D27.1 (K), D28.1 (K), D29.1 (K), D30.1 (K), U1.7 (GPIO5)
/ROW3: D37.1 (K), D38.1 (K), D39.1 (K), D40.1 (K), D41.1 (K), D42.1 (K), U1.8 (GPIO6)
/ROW4: D7.1 (K), D8.1 (K), D9.1 (K), D10.1 (K), D11.1 (K), D12.1 (K), U1.38 (GPIO26_ADC0)
/ROW5: D19.1 (K), D20.1 (K), D21.1 (K), D22.1 (K), D23.1 (K), D24.1 (K), U1.37 (GPIO25)
/ROW6: D31.1 (K), D32.1 (K), D33.1 (K), D34.1 (K), D35.1 (K), D36.1 (K), U1.36 (GPIO24)
/ROW7: D43.1 (K), D44.1 (K), D45.1 (K), D46.1 (K), D47.1 (K), D48.1 (K), U1.35 (GPIO23)
/RUN: R9.2, SW1.1, U1.26 (RUN)
/USB_D+: R2.2, U1.47 (USB_DP)
/USB_D-: R3.2, U1.46 (USB_DM)
/VBUS: F1.1, J1.A4 (VBUS), J1.A9 (VBUS), J1.B4 (VBUS), J1.B9 (VBUS), U4.5 (VBUS)
/XIN: C1.1, U1.20 (XIN), Y1.1
/XOUT: R11.1, U1.21 (XOUT)
/XOUT_X: C2.1, R11.2, Y1.2
GND: C1.2, C2.2, C3.2, C6.2, C7.2, C10.2, C11.2, C12.2, C13.2, C14.2, C15.2, C17.2, C18.2, C20.2, C22.2, J1.A1 (GND), J1.A12 (GND), J1.B1 (GND), J1.B12 (GND), J1.S1 (SHIELD), LED1.1 (K), LED2.1 (K), R5.1, R6.1, SW1.2, SW2.2, U1.19 (TESTEN), U1.57 (GND), U2.4 (GND), U3.1 (GND), U4.2 (GND)
unnamed: D1.2 (A), MX1.1
unnamed: D2.2 (A), MX2.1
unnamed: D3.2 (A), MX3.1
unnamed: D4.2 (A), MX4.1
unnamed: D5.2 (A), MX5.1
unnamed: D6.2 (A), MX6.1
unnamed: D7.2 (A), MX7.1
unnamed: D8.2 (A), MX8.1
unnamed: D9.2 (A), MX9.1
unnamed: D10.2 (A), MX10.1
unnamed: D11.2 (A), MX11.1
unnamed: D12.2 (A), MX12.1
unnamed: D13.2 (A), MX13.1
unnamed: D14.2 (A), MX14.1
unnamed: D15.2 (A), MX15.1
unnamed: D16.2 (A), MX16.1
unnamed: D17.2 (A), MX17.1
unnamed: D18.2 (A), MX18.1
unnamed: D19.2 (A), MX19.1
unnamed: D20.2 (A), MX20.1
unnamed: D21.2 (A), MX21.1
unnamed: D22.2 (A), MX22.1
unnamed: D23.2 (A), MX23.1
unnamed: D24.2 (A), MX24.1
unnamed: D25.2 (A), MX25.1
unnamed: D26.2 (A), MX26.1
unnamed: D27.2 (A), MX27.1
unnamed: D28.2 (A), MX28.1
unnamed: D29.2 (A), MX29.1
unnamed: D30.2 (A), MX30.1
unnamed: D31.2 (A), MX31.1
unnamed: D32.2 (A), MX32.1
unnamed: D33.2 (A), MX33.1
unnamed: D34.2 (A), MX34.1
unnamed: D35.2 (A), MX35.1
unnamed: D36.2 (A), MX36.1
unnamed: D37.2 (A), MX37.1
unnamed: D38.2 (A), MX38.1
unnamed: D39.2 (A), MX39.1
unnamed: D40.2 (A), MX40.1
unnamed: D41.2 (A), MX41.1
unnamed: D42.2 (A), MX42.1
unnamed: D43.2 (A), MX43.1
unnamed: D44.2 (A), MX44.1
unnamed: D45.2 (A), MX45.1
unnamed: D46.2 (A), MX46.1
unnamed: D47.2 (A), MX47.1
unnamed: D48.2 (A), MX48.1

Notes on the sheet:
Key matrix (COL2ROW, electrical 8 rows x 6 cols)
MCU (RP2040)
USB-C
Flash / power / USB ESD
Decoupling / clock / reset / boot / LEDs / USB
Mounting holes (M2): H1-H8 case / plate, H9-H12 centre cover
Power flags
eugeo: 6x4x2 ortholinear, RP2040, through-hole on show, Kailh MX hot-swap. Derived from Lumberjack by Paul James (peej), MIT License.

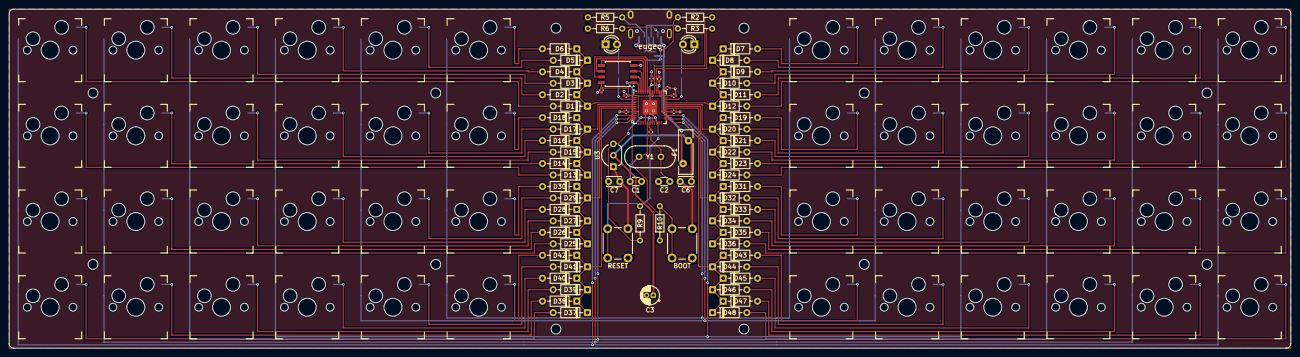
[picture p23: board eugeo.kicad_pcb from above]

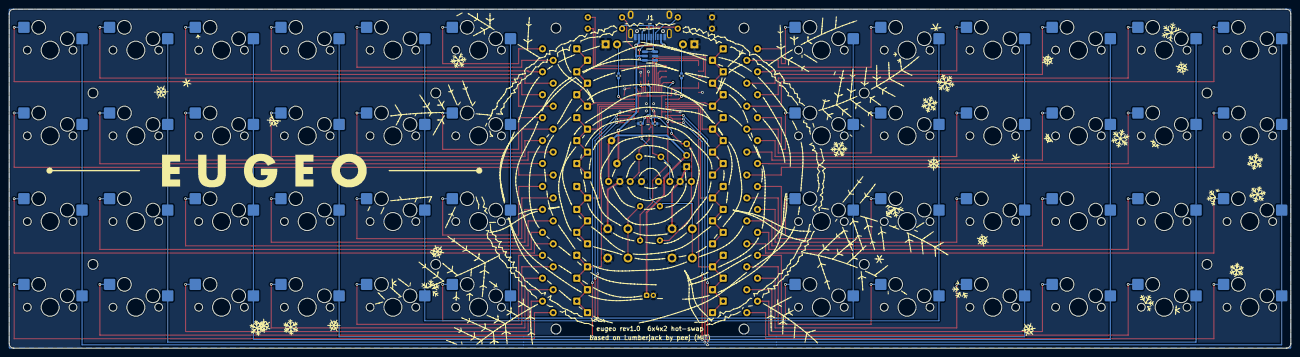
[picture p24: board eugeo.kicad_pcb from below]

Board: 2 copper layers, 284.9 x 75.4 mm, 143 parts (6 on the bottom side), 88 nets.

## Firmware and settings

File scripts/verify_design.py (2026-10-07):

"""Functional review of the routed board (run with KiCad's python).

    $KP scripts/verify_design.py [lumberjack.net]

Reads the nets straight from eugeo.kicad_pcb and checks the things DRC cannot:
RP2040 pin functions, power / +1V1 / decoupling, crystal, RUN / BOOT, QSPI flash,
USB and LED wiring, diode polarity, and that every key lands where the QMK
keyboard.json says it does.
With a Lumberjack netlist (kicad-cli sch export netlist) it also lists the
support-circuit differences from Lumberjack (expected: eugeo uses an RP2040).
"""
import json
import os
import sys

import pcbnew

sys.path.insert(0, os.path.dirname(__file__))
import sexpr  # noqa: E402

ROOT = os.path.dirname(os.path.dirname(os.path.abspath(__file__)))

# RP2040 QFN-56 pinout, from the RP2040 datasheet (section 1.4.2)
QFN56 = {1: "IOVDD", 2: "GPIO0", 3: "GPIO1", 4: "GPIO2", 5: "GPIO3", 6: "GPIO4", 7: "GPIO5",
         8: "GPIO6", 9: "GPIO7", 10: "IOVDD", 11: "GPIO8", 12: "GPIO9", 13: "GPIO10", 14: "GPIO11",
         15: "GPIO12", 16: "GPIO13", 17: "GPIO14", 18: "GPIO15", 19: "TESTEN", 20: "XIN", 21: "XOUT",
         22: "IOVDD", 23: "DVDD", 24: "SWCLK", 25: "SWD", 26: "RUN", 27: "GPIO16", 28: "GPIO17",
         29: "GPIO18", 30: "GPIO19", 31: "GPIO20", 32: "GPIO21", 33: "IOVDD", 34: "GPIO22",
         35: "GPIO23", 36: "GPIO24", 37: "GPIO25", 38: "GPIO26", 39: "GPIO27", 40: "GPIO28",
         41: "GPIO29", 42: "IOVDD", 43: "ADC_AVDD", 44: "VREG_VIN", 45: "VREG_VOUT", 46: "USB_DM",
         47: "USB_DP", 48: "USB_VDD", 49: "IOVDD", 50: "DVDD", 51: "QSPI_SD3", 52: "QSPI_SCLK",
         53: "QSPI_SD0", 54: "QSPI_SD2", 55: "QSPI_SD1", 56: "QSPI_SS", 57: "GND"}
# W25Q16JV SOIC-8 (datasheet figure 1b): pin -> RP2040 QSPI signal it must meet
FLASH = {1: "QSPI_SS", 2: "QSPI_SD1", 3: "QSPI_SD2", 4: "GND", 5: "QSPI_SD0", 6: "QSPI_SCLK",
         7: "QSPI_SD3", 8: "+3V3"}

results = []


def check(ok, msg):
    results.append((bool(ok), msg))


def main(lj_net=None):
    board = pcbnew.LoadBoard(os.path.join(ROOT, "eugeo.kicad_pcb"))
    pads, fps = {}, {}
    for fp in board.GetFootprints():
        ref = fp.GetReference()
        fps[ref] = fp
        for p in fp.Pads():
            if p.GetNumber():
                pads.setdefault((ref, p.GetNumber()), p.GetNetname().lstrip("/"))
    net = lambda ref, pin: pads.get((ref, str(pin)))
    members = {}
    for (ref, pin), n in pads.items():
        members.setdefault(n, set()).add((ref, pin))
    two = lambda ref: {net(ref, 1), net(ref, 2)}

    # --- 0. copper connectivity (independent of DRC report) --------------------
    board.BuildConnectivity()
    check(board.GetConnectivity().GetUnconnectedCount(False) == 0, "all pads connected by copper")

    # --- 1. MCU symbol pins match the datasheet ----------------------------------
    lib = sexpr.parse(open(os.path.join(ROOT, "symbols", "eugeo.kicad_sym")).read())
    sym = [s for s in lib.children("symbol") if s.items[1] == "RP2040"][0]
    names = {}
    for n in sym.walk():
        if n.tag == "pin":
            names[int(n.child("number").items[1])] = n.child("name").items[1]
    alias = {"VREG_VIN": ("VREG_VIN", "VREG_IN")}              # KiCad's library spells it VREG_IN
    bad = [p for p, f in QFN56.items() if not names.get(p, "").startswith(alias.get(f, (f,)))]
    check(not bad, f"RP2040 symbol pin names match the QFN-56 datasheet pinout (mismatch: {bad})")
    gpio_of = {}
    for pin, f in QFN56.items():
        if f.startswith("GPIO"):
            gpio_of.setdefault(net("U1", pin), []).append("GP" + f[4:])
    fn = lambda pin: net("U1", pin)

    # --- 2. power ------------------------------------------------------------------
    supply = {k: fn(k) for k, f in QFN56.items() if f in ("IOVDD", "ADC_AVDD", "VREG_VIN", "USB_VDD")}
    check(set(supply.values()) == {"+3V3"}, f"IOVDD x6, ADC_AVDD, VREG_VIN, USB_VDD on +3V3 {supply}")
    check(fn(45) == fn(23) == fn(50) == "+1V1", "VREG_VOUT (45) feeds DVDD (23, 50) on +1V1")
    check(fn(57) == "GND" and fn(19) == "GND", "exposed pad and TESTEN (19) on GND")
    check({net("U3", 1), net("U3", 2), net("U3", 3)} == {"GND", "+5V", "+3V3"} and net("U3", 1) == "GND"
          and net("U3", 2) == "+5V" and net("U3", 3) == "+3V3", "MCP1700 TO-92: 1 GND, 2 VIN (+5V), 3 VOUT (+3V3)")
    vb = {net("J1", p) for p in ("A4", "A9", "B4", "B9")}
    check(vb == {"VBUS"} and two("F1") == {"VBUS", "+5V"}, "VBUS pins -> F1 polyfuse -> +5V")
    check(two("C3") == {"+5V", "GND"} and net("C3", 1) == "+5V", "C3 electrolytic + (pad 1) on +5V")
    check(two("C6") == {"+5V", "GND"} and two("C7") == {"+3V3", "GND"}, "MCP1700 input (C6) / output (C7) capacitors")
    caps = {r: fps[r] for r in fps if r.startswith("C") and fps[r].GetValue() in ("100n", "1u")}
    c33 = [r for r in caps if two(r) == {"+3V3", "GND"}]
    c11 = [r for r in caps if two(r) == {"+1V1", "GND"}]
    check(len(c33) >= 6 and len(c11) >= 3, f"decoupling: {len(c33)} on +3V3 {sorted(c33)}, {len(c11)} on +1V1 {sorted(c11)}")
    check(fps["C17"].GetValue() == "1u" and net("C17", 1) == "+3V3" and fps["C18"].GetValue() == "1u"
          and net("C18", 1) == "+1V1", "1 uF on VREG_VIN (C17) and VREG_VOUT (C18)")
    u1 = fps["U1"].GetPosition()
    far = [r for r in c33 + c11 if r not in ("C22", "C7") and (caps[r].GetPosition() - u1).EuclideanNorm() > pcbnew.FromMM(7)]
    check(not far, f"MCU decoupling within 7 mm of the RP2040 (too far: {far})")

    # --- 3. clock / reset / boot / flash ------------------------------------------
    check(fps["Y1"].GetValue() == "12MHz", "12 MHz crystal (RP2040 boot ROM / USB PLL)")
    check(net("Y1", 1) == fn(20) == "XIN", "Y1 pin 1 on XIN (20)")
    check(two("R11") == {fn(21), net("Y1", 2)} and fps["R11"].GetValue() == "1k", "XOUT (21) -> R11 1k -> Y1 pin 2")
    check(two("C1") == {"XIN", "GND"} and two("C2") == {net("Y1", 2), "GND"}
          and fps["C1"].GetValue() == fps["C2"].GetValue() == "22p", "22 pF load capacitors on both crystal pins")
    check(fn(26) == "RUN" and two("R9") == {"+3V3", "RUN"} and two("SW1") == {"RUN", "GND"},
          "RUN (26): 10k pull-up R9, RESET button SW1 to GND")
    check(two("R10") == {fn(56), "BOOTSEL"} and two("SW2") == {"BOOTSEL", "GND"},
          "BOOT button SW2 pulls QSPI_SS (56) low through R10 1k")
    for pin, want in FLASH.items():
        if want.startswith("QSPI"):
            k = [p for p, f in QFN56.items() if f == want][0]
            check(net("U2", pin) == fn(k), f"flash pin {pin} -> RP2040 {want} ({k})")
        else:
            check(net("U2", pin) == want, f"flash pin {pin} on {want}")
    check(two("C22") == {"+3V3", "GND"}, "flash VCC decoupled by C22")

    # --- 4. USB (full speed) --------------------------------------------------------
    dp, dm = net("J1", "A6"), net("J1", "A7")
    check(net("J1", "B6") == dp and net("J1", "B7") == dm, "USB-C D+ (A6/B6) and D- (A7/B7) pairs joined")
    check(two("R2") == {dp, fn(47)} and fps["R2"].GetValue() == "27R", "D+ -> R2 27R -> USB_DP (47)")
    check(two("R3") == {dm, fn(46)} and fps["R3"].GetValue() == "27R", "D- -> R3 27R -> USB_DM (46)")
    check(net("U4", 1) == net("U4", 6) == dp and net("U4", 3) == net("U4", 4) == dm
          and net("U4", 2) == "GND" and net("U4", 5) == "VBUS", "USBLC6-2SC6 on the connector side of D+/D-, GND, VBUS")
    for cc, r in (("A5", "R5"), ("B5", "R6")):
        check(two(r) == {net("J1", cc), "GND"} and fps[r].GetValue() == "5.1k",
              f"CC {cc} -> {r} 5.1k -> GND (5 V from USB-C hosts)")
    check({net("J1", p) for p in ("A1", "A12", "B1", "B12", "S1")} == {"GND"}, "USB GND + shield on GND")

    check(fn(24).startswith("unconnected") and fn(25).startswith("unconnected"),
          "SWCLK / SWDIO (24, 25) left open (flashing is over USB)")

    # --- 5. LEDs -------------------------------------------------------------------
    kb = json.load(open(os.path.join(ROOT, "firmware/qmk/keyboards/eugeo/keyboard.json")))
    for led, r in (("LED1", "R7"), ("LED2", "R8")):
        a = net(led, 2)
        mcu = ({net(r, 1), net(r, 2)} - {a}).pop()
        check(net(led, 1) == "GND" and gpio_of.get(mcu), f"{led}: cathode (pad 1) GND, anode via {r} to {gpio_of.get(mcu)}")
    caps = kb["indicators"]["caps_lock"]
    check(gpio_of[net("R7", 1)] == [caps], f"QMK caps_lock pin {caps} drives LED1")
    src = open(os.path.join(ROOT, "firmware/qmk/keyboards/eugeo/eugeo.c")).read()
    check(f"#define LAYER_LED {gpio_of[net('R8', 1)][0]}" in src, f"eugeo.c layer LED pin is {gpio_of[net('R8', 1)]} (LED2)")
    check(kb["processor"] == "RP2040" and kb["bootloader"] == "rp2040", "QMK processor RP2040 / bootloader rp2040")

    # --- 6. matrix vs QMK ----------------------------------------------------------
    check(kb["diode_direction"] == "COL2ROW", "diode_direction COL2ROW")
    rows = kb["matrix_pins"]["rows"]
    cols = kb["matrix_pins"]["cols"]
    used = rows + cols
    check(len(set(used)) == len(used), "matrix pins unique")
    check(all(p in sum(gpio_of.values(), []) for p in used), "every matrix pin is an RP2040 GPIO wired on the board")
    layout = kb["layouts"]["LAYOUT_ortho_4x12"]["layout"]
    diode_of = {}
    for ref, fp in fps.items():
        if ref.startswith("D") and ref[1:].isdigit() and int(ref[1:]) <= 48:
            diode_of[net(ref, 2)] = ref
    seen, errors = set(), []
    for i, k in enumerate(layout):
        r, c = divmod(i, 12)
        mr, mc = k["matrix"]
        mx = f"MX{r * 12 + c + 1}"
        fp = fps[mx]
        if (k["x"], k["y"]) != (c, r):
            errors.append(f"{mx} layout position")
        col_port = gpio_of.get(net(mx, 2))
        d = diode_of.get(net(mx, 1))
        if d is None:
            errors.append(f"{mx}: no diode on switch pad 1")
            continue
        row_port = gpio_of.get(net(d, 1))
        if col_port != [cols[mc]]:
            errors.append(f"{mx}: column {col_port} != {cols[mc]}")
        if row_port != [rows[mr]]:
            errors.append(f"{mx}: row {row_port} != {rows[mr]}")
        if (mr, mc) in seen:
            errors.append(f"{mx}: duplicate matrix position")
        seen.add((mr, mc))
        pad1 = fps[d].FindPadByNumber("1")
        if pad1.GetShape() not in (pcbnew.PAD_SHAPE_RECT, pcbnew.PAD_SHAPE_ROUNDRECT):
            errors.append(f"{d}: pad 1 is not the square cathode pad")
    xs = [fps[f"MX{c + 1}"].GetPosition().x for c in range(12)]
    ys = [fps[f"MX{r * 12 + 1}"].GetPosition().y for r in range(4)]
    check(xs == sorted(xs) and ys == sorted(ys), "MX1..MX48 are placed left->right, top->bottom like the layout")
    check(not errors, f"all 48 keys: switch -> diode (anode) -> row, switch -> column, as keyboard.json says {errors[:5]}")
    for p in rows:
        n = [k for k, v in gpio_of.items() if v == [p]][0]
        check(sum(1 for ref, _ in members[n] if ref.startswith("D")) == 6, f"{p} row has 6 diode cathodes")
    for p in cols:
        n = [k for k, v in gpio_of.items() if v == [p]][0]
        check(sum(1 for ref, _ in members[n] if ref.startswith("MX")) == 8, f"{p} column has 8 switches")

    # --- 7. diff against Lumberjack ------------------------------------------------
    if lj_net:
        lj = sexpr.parse(open(lj_net).read())
        ljpads = {}
        for n in lj.child("nets").children("net"):
            for node in n.children("node"):
                ljpads[(node.child("ref").items[1], node.child("pin").items[1])] = n.child("name").items[1]
        rename = {"D61": "D49", "D62": "D50"}
        skip = lambda ref: ref.startswith(("MX", "2u_", "J3", "J4", "J5", "H")) or (
            ref.startswith("D") and ref[1:].isdigit() and int(ref[1:]) <= 60)

        def groups(padmap, rn):
            g = {}
            for (ref, pin), n in padmap.items():
                ref = rn.get(ref, ref)
                if skip(ref) or n.startswith("unconnected"):
                    continue
                g.setdefault(n, set()).add(f"{ref}.{pin}")
            return {frozenset(v) for v in g.values()}
        a, b = groups(ljpads, rename), groups(pads, {})
        diff_lj = sorted(sorted(s) for s in a - b)
        diff_eu = sorted(sorted(s) for s in b - a)
        print("\nLumberjack-only connection groups:")
        for s in diff_lj:
            print("  ", s)
        print("eugeo-only connection groups:")
        for s in diff_eu:
            print("  ", s)

    print()
    for ok, msg in results:
        print("PASS" if ok else "FAIL", msg)
    print(f"\n{sum(ok for ok, _ in results)}/{len(results)} checks passed")


if __name__ == "__main__":
    main(sys.argv[1] if len(sys.argv) > 1 else None)

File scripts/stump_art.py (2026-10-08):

"""Back-side artwork: a frozen tree stump (run with KiCad's python, after routing).

    $KP scripts/stump_art.py eugeo.kicad_pcb

Tree rings, a bark rim and drying cracks sit in the middle of the back, frost ferns
creep out towards both ends and snowflakes are scattered over the keys. Everything
is B.Silkscreen, clipped around every exposed pad, hole and existing text, except a
few large snowflakes that are B.Mask openings on the GND pour (bare, tin-plated copper
under a blue mask reads as ice). Those are only placed where the pour is solid GND
with no track or via underneath. Re-running replaces the previous artwork.
"""
import json
import math
import os
import random
import sys

import pcbnew

sys.path.insert(0, os.path.dirname(__file__))
import design  # noqa: E402

ART = "stump-art"            # group name; the previous run's group is removed first
CX, CY = design.CENTER_X, (design.EDGE[1] + design.EDGE[3]) / 2
W_RING, W_BARK, W_FROST = 0.15, 0.2, 0.15
# logo: Futura "EUGEO" (scripts/logo_eugeo.json) in the free band between key rows 1
# and 2 of the right-hand block (front view), i.e. on the left when the board is turned over
LOGO_C = ((design.KEY_X[6] + design.KEY_X[11]) / 2, (design.KEY_Y[1] + design.KEY_Y[2]) / 2 - 1.8)
LOGO_RULE = (5.0, 20.0)      # gap after the text, rule length

PAD_MARGIN = 0.35            # silk to mask opening
EDGE_MARGIN = 0.8
STEP = 0.25                  # clipping resolution (mm)

P = lambda x, y: pcbnew.VECTOR2I(pcbnew.FromMM(x), pcbnew.FromMM(y))
mm = pcbnew.ToMM


# ---- drawing ----------------------------------------------------------------------
def ring(r, rng, sx=1.12, wob=0.035, n=None):
    """Closed wobbly ring around the pith (a bit wider than tall, like a sawn log)."""
    n = n or max(48, int(r * 9))
    ph = [rng.uniform(0, 2 * math.pi) for _ in range(4)]
    pts = []
    for i in range(n + 1):
        t = 2 * math.pi * i / n
        k = (1 + wob * math.sin(3 * t + ph[0]) + wob * 0.6 * math.sin(5 * t + ph[1])
             + wob * 0.4 * math.sin(9 * t + ph[2]) + 0.02 * math.sin(2 * t + ph[3]))
        pts.append((CX + sx * r * k * math.cos(t), CY + r * k * math.sin(t)))
    return pts


def bark(r, rng):
    """Jagged rim: small random bites out of the outer ring."""
    n = int(r * 14)
    pts = []
    for i in range(n + 1):
        t = 2 * math.pi * i / n
        rr = r + (rng.uniform(-0.9, 0.2) if i % 3 == 0 else rng.uniform(-0.25, 0.25))
        if i == n:
            pts.append(pts[0])
            break
        pts.append((CX + 1.12 * rr * math.cos(t), CY + rr * math.sin(t)))
    return pts


def crack(angle, r_out, depth, rng):
    """Drying check: a narrow V from the rim towards the pith, slightly kinked."""
    out = []
    for side in (-1, 1):
        pts = []
        for i in range(9):
            f = i / 8
            r = r_out - depth * f
            a = angle + side * 0.035 * (1 - f) + 0.02 * math.sin(f * 7 + angle)
            pts.append((CX + 1.12 * r * math.cos(a), CY + r * math.sin(a)))
        out.append(pts)
    return out


def fern(x, y, ang, length, rng, depth=0):
    """Frost fern: a gently curving stem with sparse 60 degree side branches."""
    segs = []
    pts = [(x, y)]
    n = max(3, int(length / 1.6))
    bend = rng.uniform(-0.03, 0.03)
    for i in range(1, n + 1):
        f = i / n
        ang += bend
        x += (length / n) * math.cos(ang)
        y += (length / n) * math.sin(ang)
        pts.append((x, y))
        if depth == 0 and i % 2 == 0 and i < n - 1:
            bl = length * 0.32 * (1 - f) + 1.0
            for s in (-1, 1):
                if rng.random() < 0.8:
                    segs += fern(x, y, ang + s * math.radians(60), bl, rng, 1)
        elif depth == 1 and i % 2 == 1 and i < n and length > 4:
            for s in (-1, 1):
                b = ang + s * math.radians(60)
                bl = 0.9 * (1 - f) + 0.4
                segs.append([(x, y), (x + bl * math.cos(b), y + bl * math.sin(b))])
    segs.append(pts)
    return segs


def flake(x, y, r, rot=0.0):
    """Six-armed snowflake with two pairs of barbs per arm (list of polylines)."""
    out = []
    for k in range(6):
        a = rot + k * math.pi / 3
        ex, ey = x + r * math.cos(a), y + r * math.sin(a)
        out.append([(x, y), (ex, ey)])
        for f, bl in ((0.45, 0.35), (0.72, 0.25)):
            bx, by = x + f * r * math.cos(a), y + f * r * math.sin(a)
            for s in (-1, 1):
                b = a + s * math.radians(55)
                out.append([(bx, by), (bx + bl * r * math.cos(b), by + bl * r * math.sin(b))])
    return out


# ---- obstacles ------------------------------------------------------------------------
class Keepout:
    """Fast 'is this point too close to an exposed pad / hole / silk text / edge?'."""

    def __init__(self, board, extra=(), boxes=()):
        self.cell = 4.0
        self.grid = {}
        self.items = []
        for fp in board.GetFootprints():
            for p in fp.Pads():
                if p.IsOnLayer(pcbnew.B_Mask) or p.GetDrillSize().x > 0:
                    self.add(p.GetBoundingBox(), ("pad", p))
            for t in [fp.Reference(), fp.Value()] + [g for g in fp.GraphicalItems() if g.GetClass() == "PCB_TEXT"]:
                if t.IsVisible() and t.GetLayer() == pcbnew.B_SilkS:
                    self.add(t.GetBoundingBox(), ("box", t.GetBoundingBox()))
        for d in board.GetDrawings():
            if d.GetLayer() == pcbnew.B_SilkS and isinstance(d, pcbnew.PCB_TEXT):
                self.add(d.GetBoundingBox(), ("box", d.GetBoundingBox()))
        for (x1, y1, x2, y2) in boxes:
            bb = pcbnew.BOX2I(P(x1, y1), P(x2 - x1, y2 - y1))
            self.add(bb, ("box", bb))
        for (x, y, r) in extra:
            bb = pcbnew.BOX2I(P(x - r, y - r), P(2 * r, 2 * r))
            self.add(bb, ("circle", (x, y, r)))
        self.acc = pcbnew.FromMM(PAD_MARGIN)
        x1, y1, x2, y2 = design.EDGE
        self.edge = (x1 + EDGE_MARGIN, y1 + EDGE_MARGIN, x2 - EDGE_MARGIN, y2 - EDGE_MARGIN)

    def add(self, bb, item):
        self.items.append(item)
        i = len(self.items) - 1
        m = PAD_MARGIN + 0.5
        gx1, gy1 = int((mm(bb.GetLeft()) - m) // self.cell), int((mm(bb.GetTop()) - m) // self.cell)
        gx2, gy2 = int((mm(bb.GetRight()) + m) // self.cell), int((mm(bb.GetBottom()) + m) // self.cell)
        for gx in range(gx1, gx2 + 1):
            for gy in range(gy1, gy2 + 1):
                self.grid.setdefault((gx, gy), []).append(i)
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

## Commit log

2026-10-06 Add eugeo: 6x4x2 hot-swap keyboard derived from Lumberjack
    48-key through-hole ortholinear keyboard based on peej/lumberjack-keyboard
    with Kailh MX hot-swap sockets, plus switch plate, Mojo60-style SLA case,
    plate/case foam, JLCPCB fabrication and socket assembly files, and QMK
    firmware with VIA/Remap support. Schematic and PCB are generated from
    scripts/design.py.
    [eugeo-bom.csv, eugeo-bottom.dxf, eugeo-bottom.kicad_pcb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]
2026-10-07 Add centre component cover
    Lumberjack-style 2 mm acrylic cover over the diode stacks, MCU and USB-C,
    held by four M2 10 mm standoffs. Adds mounting holes H9-H12 to the PCB
    (rerouted, DRC clean, 49/49 functional checks), cover outline/DXF/gerbers,
    a STEP/STL model, and a clearance check against parts and the case.
    [eugeo-case.step, eugeo-cover.dxf, eugeo-cover.kicad_pcb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]
2026-10-07 Add Yushakobo laser-cut SVGs and pre-order checks
    - lasercut/yushakobo: centre cover (clear acrylic 2 mm), switch plates
    (POM 1.5 mm) and plate/case foams (PORON 3 mm) laid out on Yushakobo's
    official Inkscape templates, with export and rule-check scripts
    - plate foam: 3 mm PORON, standoff holes 4.4 mm to keep a 1 mm web
    - scripts/preorder_check.py: revision diff, placement, hardware vs exposed
    copper, via tenting, JLCPCB minimums, Gerber freshness, drill/CPL/plate
    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
    [eugeo-case-foam.dxf, eugeo-case-foam.kicad_pcb, eugeo-plate-foam.dxf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]
2026-10-07 Add assembled renders and refresh PCB renders
    Renders of the case with PCB, switch plates, centre cover and placeholder
    switches/keycaps (scripts/preview_models.py), plus PCB renders of the
    current board with the cover holes.
2026-10-07 Raise the case rim to hide the switch tops
    Rim height from plate + 4.0 mm to plate + 6.5 mm (front 23.1 mm, back
    32.9 mm). Keycaps still clear the walls by ~1.1 mm; no interference with
    the PCB, parts or centre cover. Renders refreshed.
    [eugeo-case.step, eugeo-case.stl, eugeo-cover.step]
2026-10-07 Switch to RP2040, zigzag diodes and a frozen-stump back
    - MCU: ATmega328P + V-USB -> RP2040 + W25Q16 QSPI flash, 12 MHz crystal,
    MCP1700 3.3 V LDO, USBLC6 ESD and 27R series resistors. SMD parts are
    assembled by JLCPCB (BOM/CPL now include them); everything else stays
    through-hole and on show.
    - RP2040 block is hand-routed: +3V3 ring inside the pin ring, +1V1 via the
    back, QSPI / crystal / decoupling / row and column escapes. ISP and SWD
    headers dropped (UF2 flashing over USB with BOOT + RESET).
    - Diode stacks zigzag like Lumberjack.
    - Back side artwork: frozen tree stump with frost ferns and snowflakes,
    some as bare-copper mask openings (scripts/stump_art.py).
    - QMK: RP2040 / rp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
    [eugeo-bom.csv, eugeo-bottom.dxf, eugeo-bottom.kicad_pcb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]
2026-10-08 Move the status LEDs to the top, side by side
    LED1 / LED2 now sit next to each other above the QSPI flash. They are
    driven from the two topmost left GPIOs (GP2 / GP1) through 0402 resistors
    on the back, which frees the crowded bottom-right corner. Left rows move
    to GP3-GP6; QMK pins and the UF2 builds follow.
    [eugeo-bom.csv, eugeo.kicad_pcb, eugeo.kicad_sch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]
2026-10-08 Balance the centre layout: LEDs left and right, parts mirrored
    - One LED on each side at the top (under R5/R6 and R2/R3), driven from the
    topmost left / right GPIO (GP1 / GP28); right rows move to GP23-GP26.
    - USB D+/D- go round the right LED to R2/R3.
    - Lower parts mirrored about the centre line: U3 | crystal | F1, the four
    disc capacitors in one row, R9 / R10 between RESET and BOOT, C3 centred.
    [eugeo.kicad_pcb, eugeo.kicad_sch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]
2026-10-08 Cover screws at the corners and a large EUGEO logo on the back
    - Centre cover holes move to the four corners of the acrylic
    (131.5 / 173.3 x 59.4 / 126.3). The column buses along the bottom edge
    split around the lower screws: COL5 / COL4 above, COL3..COL0 below.
    - Back side: Futura "EUGEO" (same face as the case nameplate), 7.5 mm cap
    height with a rule and dot each side, in the free band between key rows
    1 and 2. Letters are pre-outlined by scripts/logo_outline.py into
    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
    [eugeo-bottom.dxf, eugeo-bottom.kicad_pcb, eugeo-case.step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]
2026-10-08 JLCPCB PCBA: fix flash / USBLC6 rotation, record the upload check
    Checked in JLCPCB's placement preview: the SOIC-8 flash (top) and the
    SOT-23-6 USBLC6 (bottom) need +270 / +90 on top of KiCad's angle so pin 1
    and the leads land on the footprint. All 7 BOM lines matched LCSC parts.
    [eugeo-cpl.csv]
2026-10-08 Add full-assembly BOM/CPL for JLCPCB
    export_jlc_pcba.py --full also places the USB-C and every through-hole
    part (pad centres, LED and USB-C rotated 180 for JLCPCB's models).
    Quote checked: 22 BOM lines matched, 5 boards ¥27,679.
    [eugeo-bom.csv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]

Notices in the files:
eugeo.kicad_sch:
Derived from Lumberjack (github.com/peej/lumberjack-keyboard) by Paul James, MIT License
